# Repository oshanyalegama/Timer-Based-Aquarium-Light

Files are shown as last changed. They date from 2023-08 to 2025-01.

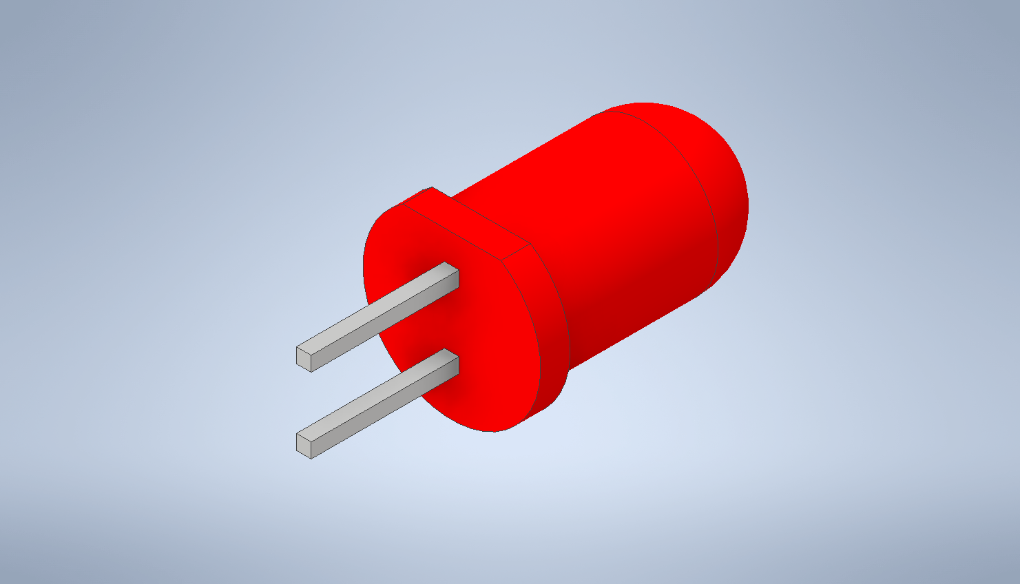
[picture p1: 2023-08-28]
Enclosure/Initial Design/Solidworks/BTG_901_BT_001_LED_5mm_Rot/LED_5mm_Rot.bmp

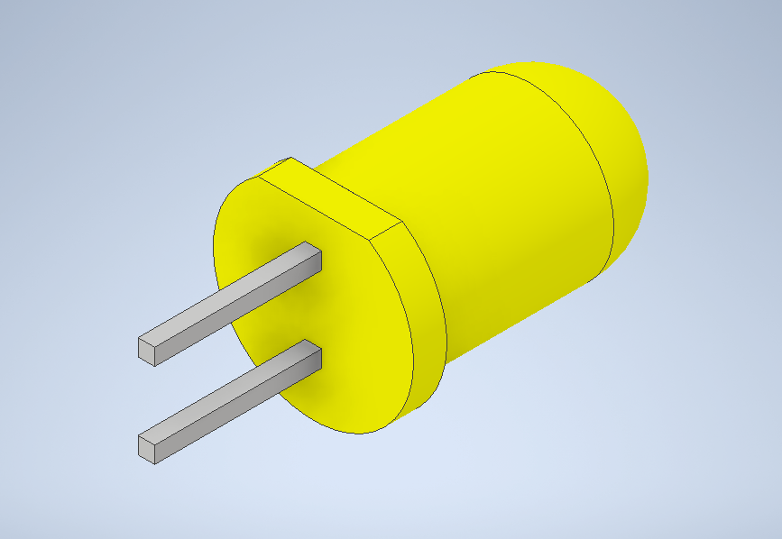
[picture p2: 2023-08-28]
Enclosure/Initial Design/Solidworks/BTG_901_BT_002_LED_5mm_Yellow/LED_5mm_Yellow.bmp

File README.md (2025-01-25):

# Timer-Based Aquarium Light

This project presents a **timer-based aquarium light**, an innovative and user-friendly solution for aquarium maintenance. The device automates light exposure for aquarium fish and plants, ensuring optimal health and growth. Designed for simplicity, the system is powered by the **ATmega328P microcontroller** and integrates an **Arduino Relay Module** for seamless switching based on time.



## Key Features
- **Programmable Timers**: Choose between three preset durations (8, 10, or 12 hours), ideal for different aquatic species and environmental needs.
- **Easy Reset**: A long-press reset button simplifies reconfiguration.
- **User-Friendly Design**: Visual indicators (LEDs) display the active timer setting, making it intuitive to use.
- **Compact and Lightweight**: Enclosure dimensions: 12cm x 7cm x 50cm, weighing less than 100g.
- **Universal Compatibility**: Designed for aquarium lights operating at 12V DC.

## Implementation
The system comprises:
1. **Power Supply Unit**: Converts 240V AC to 12V DC for operation.
2. **Control Unit**: Processes user inputs and manages timer functions using the ATmega328P microcontroller.
3. **Relay Module**: Controls power delivery to the aquarium light.
4. **Indicator LEDs**: Display the selected timer option.
5. **Enclosure**: A robust, 3D-printed housing protects components while ensuring aesthetic appeal.

## Tests and Validation
- Verified power delivery and relay functionality.
- Buttons tested for reliable activation of timer settings.

## Technologies Used
- **ATmega328P Microcontroller**: Core logic unit.
- **Arduino IDE**: Used for programming and debugging.
- **SolidWorks**: For enclosure design.
- **Altium**: For PCB design

---

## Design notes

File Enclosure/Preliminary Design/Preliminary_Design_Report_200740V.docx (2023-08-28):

University of Moratuwa - Wikipedia

Department of Electronic and Telecommunication Engineering

University of Moratuwa

Preliminary Design Report

Yalegama M.M.O.A.B : 200740V

This report is submitted as a partial fulfilment of the module

EN2160 - Electronic Design Realization

15th June 2023

Initial Design

Schematic

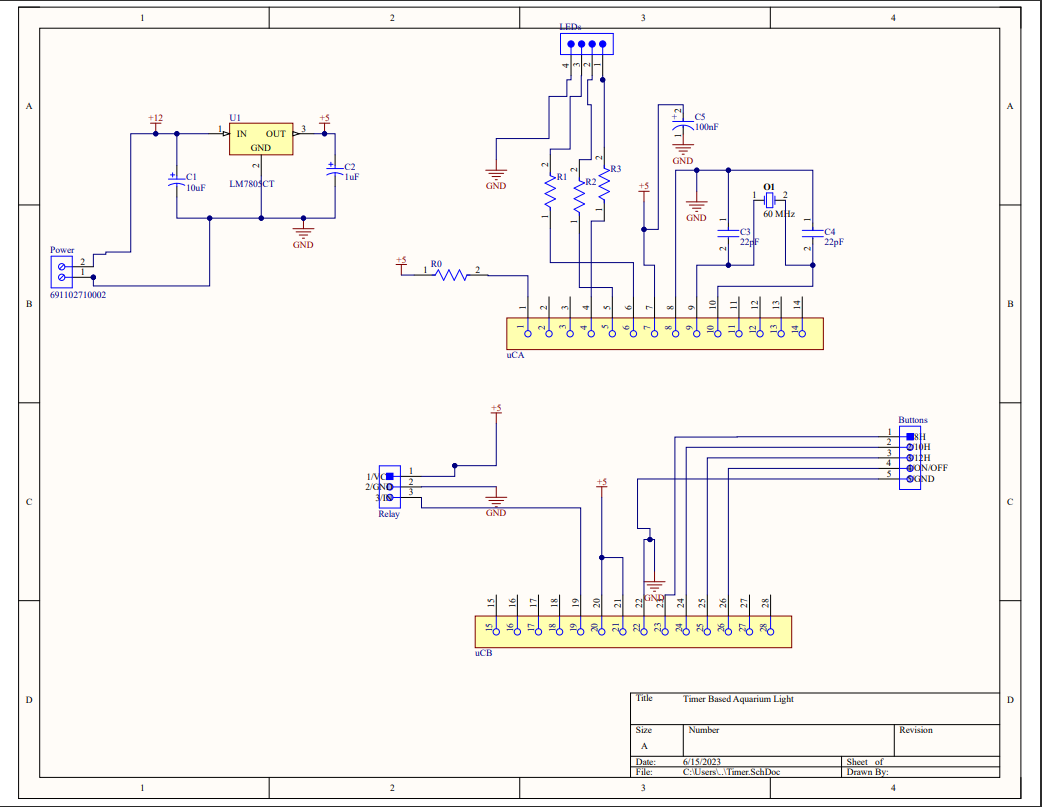
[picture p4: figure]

Enclosure

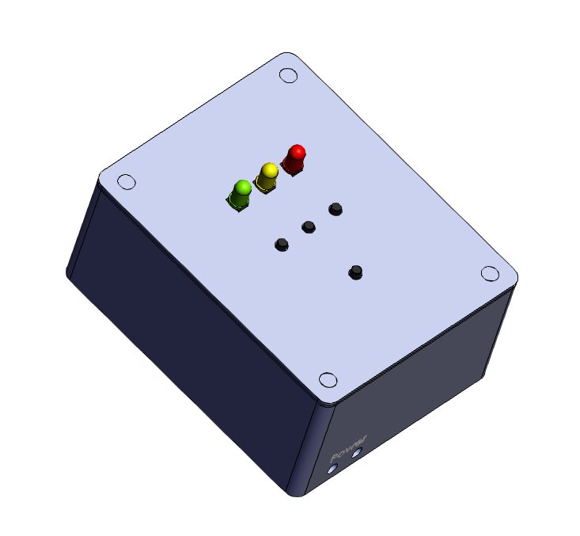
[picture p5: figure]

Problems with the initial design

After studying the course content delivered by Prof. Jayasinghe there were key problems identified about the initial design of the product.

- The enclosure had too many sharp edges that restricted it from being molded, which would be necessary for mass production.
- The design of the device was not informed by user feedback and hence the success of the product was questionable.
- The schematic documentation was not organized according to the industry standards.
- The simplicity of the device’s functionality wasn’t justified by the cost.

Upon discussing with the members of my group and inquiring users on feedback about the initial design, some problems about the initial design were found.

- The design of the enclosure wasn’t impressive in an aesthetic sense.
- The device didn’t provide enough functionality.
- The functionality provided by the device wasn’t sufficient compared to the cost of the product.
- The user interface was not informative enough and the user didn’t receive enough information regarding the operation of the device.

Considering these discoveries, the enclosure and functionality of the new design of the product was made such that these problems were addressed, and the suggested improvements were incorporated.

Enclosure:

The newer enclosure has fillet edges and sides with draft angles that make it possible to be molded for mass production. The enclosure was made to be aesthetically pleasing and unique. The enclosure contains a more advanced UI, with an LCD to display the state of the timer and a button pad to navigate the menu.

Schematic:

The newer schematic is more compliant with the industry standard rules. It added an LCD module for added functionality and to make more efficient use of the capability of the Atmega328P chip. The functionality of the device was also expanded, using the microcontroller to set user defined times instead of fixed times as was before.

Final Design

Schematic

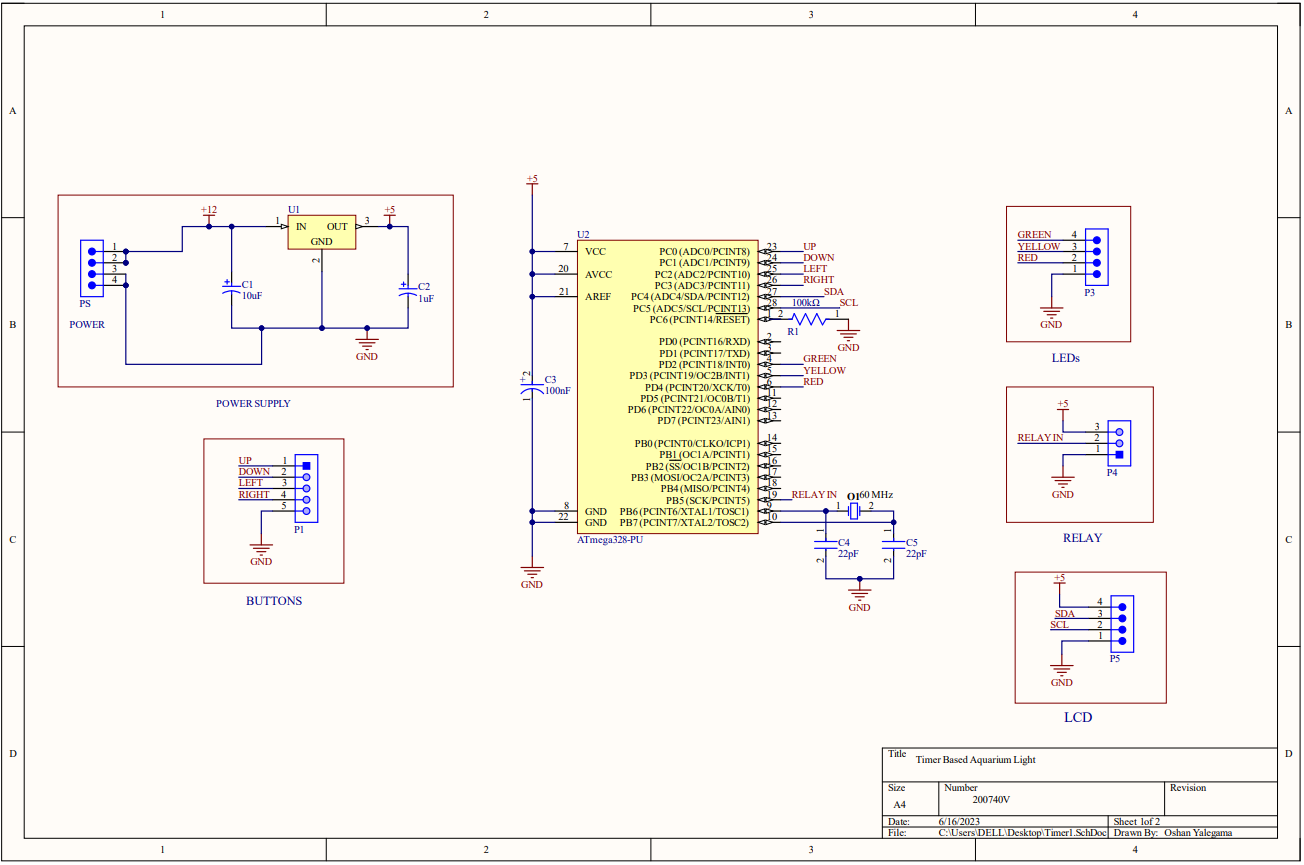
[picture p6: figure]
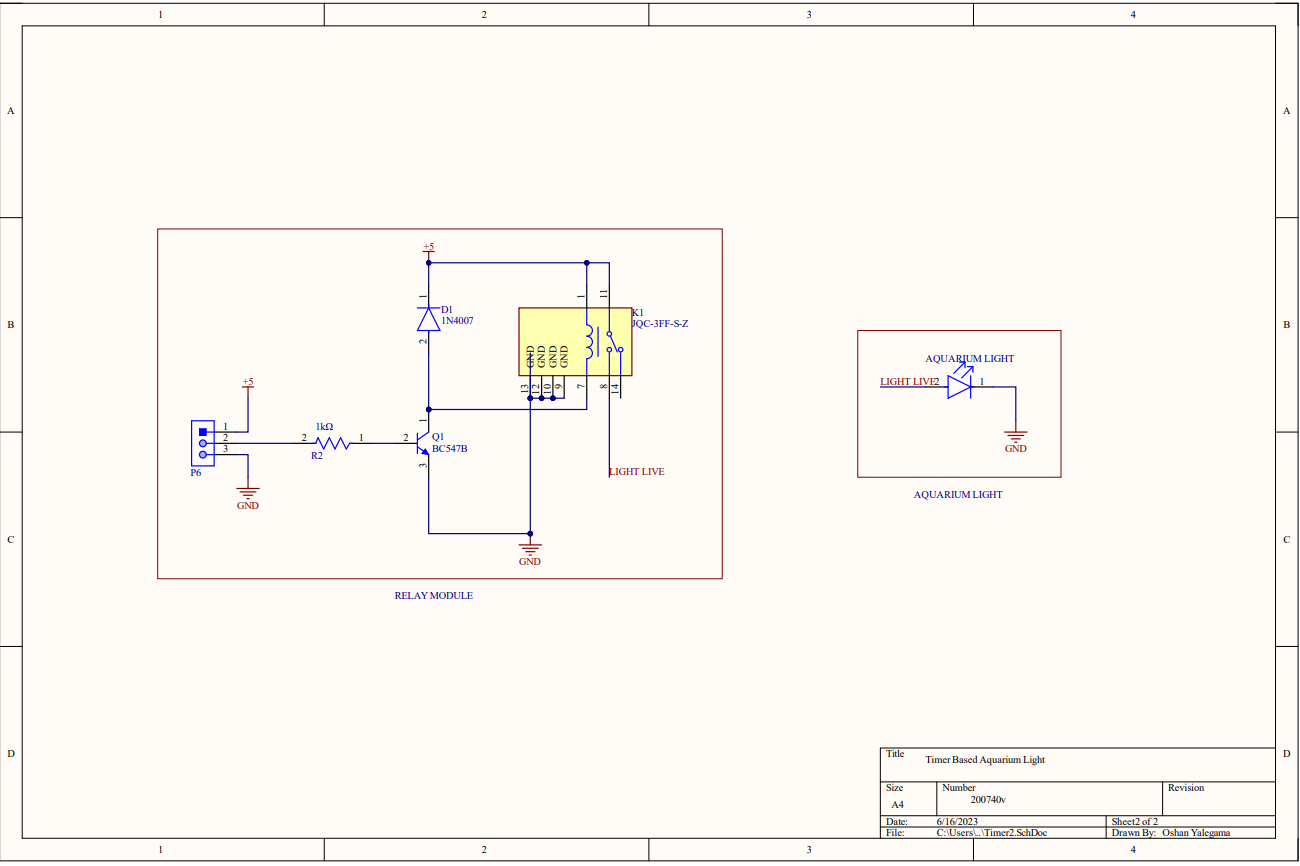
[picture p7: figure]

Enclosure

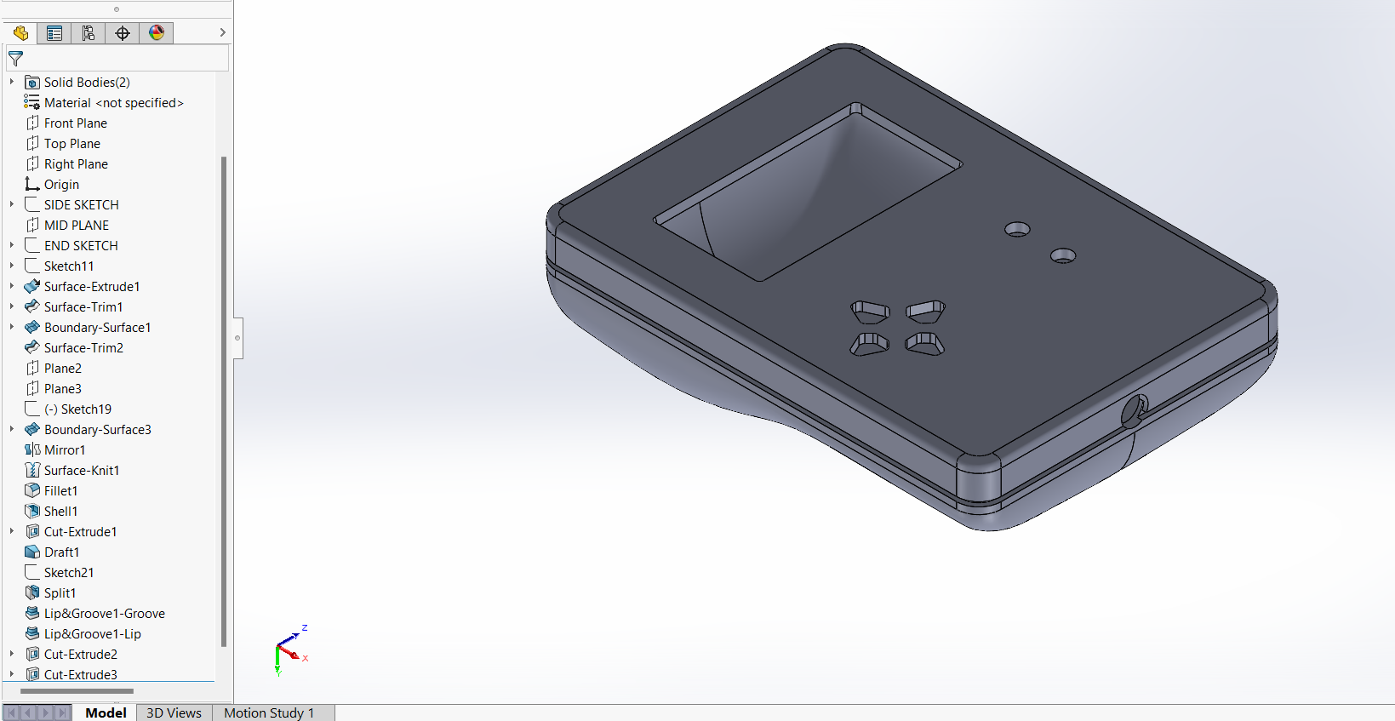
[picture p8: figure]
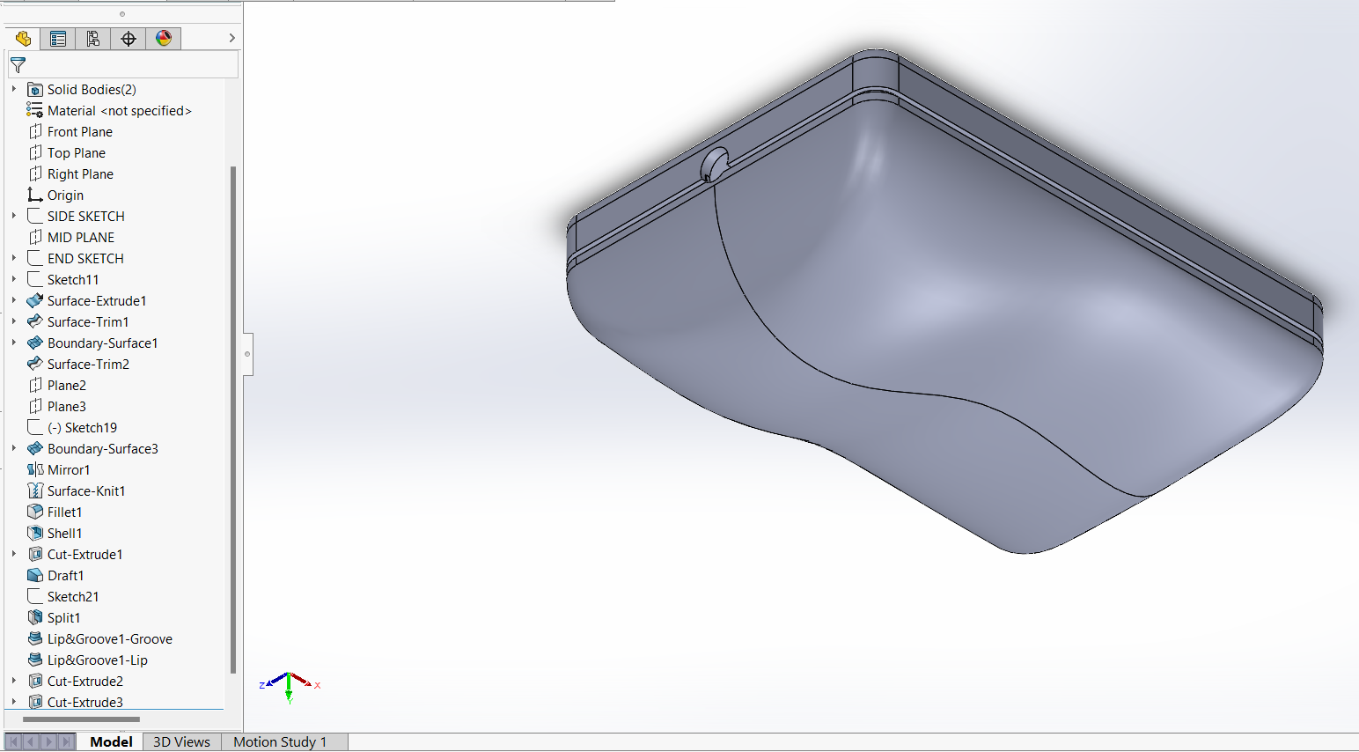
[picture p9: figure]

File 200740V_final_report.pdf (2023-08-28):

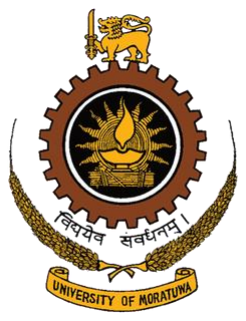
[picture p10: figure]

Department of Electronic and Telecommunication Engineering

University of Moratuwa

Timer Based Aquarium Light

Yalegama M.M.O.A.B : 200740V

This report is submitted as a partial fulfilment of the module

EN2160 - Electronic Design Realization

26th July 2023

## Contents

## Abstract

The aim of this project was to create a timer-based aquarium light which is a device that can be used in fish tanks to light the fish tank for a specified period. The user has 3 options to select from for the period with the added feature of being able to turn it off and on as normal use. The project utilized the ATmega328p microcontroller and the Arduino Relay module to deliver a switching action based on time. The final design of the product operated at a voltage of 12V and was suitable for use with aquarium lights with rated operating voltage of 12V.

## 1. Introduction

### 1.1 Problem Description and Overview

Contrary to popular belief, fish keeping can be a very delicate task in terms of maintenance. Ensure the fish and plants in the aquarium tank get the proper amount of nutrition and exposure to light is critical. The amount of light especially can be a rather tedious to control since it’s a daily activity that requires careful timing. The time of exposure to light also depends on several factors such as the species of fish and the amount of ambient light. However, it typically ranges between 8 and 12 hours per day.

This problem is addressed by creating an aquarium light based on a timer that will turn off after one of three specified times, namely, 8, 10, and 12. This is indicated by 3 led lights on the enclosure.

### 1.2 Functionality and key features

The product consists of an aquarium light that turns off after a set interval of time. The timer options are selected according to the requirements of fish and plant life to thrive. The device can be used in medium sized tanks and light should be attached to the rood of the fish tank. The recommended timer option for a medium sized fish tank is 8 hours and should be turned on between sun rise and sun set.

Reset feature – By holding the on/off button for a 5 second duration it resets any timer feature that had been turned on at that time.

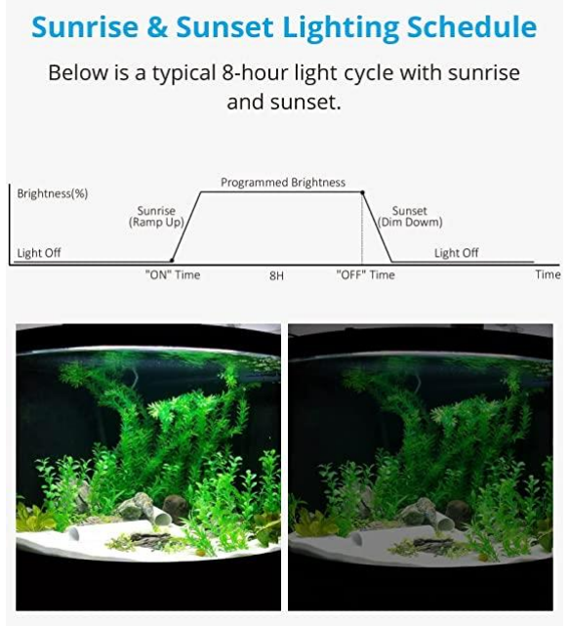
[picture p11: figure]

### 1.3 Specifications

Size – 12 cm length x 7 cm width x 50 cm height

Weight – less than 100g

Enclosure Colour – Black

LED Colours – Green, Yellow and Red and red to indicate 8 hours, 10 hours and 12 hours respectively.

Operation Mode - On or Off

Operating Voltage - Power supply should be connected to 240V / 60Hz supply. LED lights operate at 12V DC.

Timing Options - Three sets of timers. 8H, 10H and 12H.

Additional features –

Easy to set up device.

Simple and easy to use User Interface

## 2. Implementation

### 2.1 Functional Block diagram

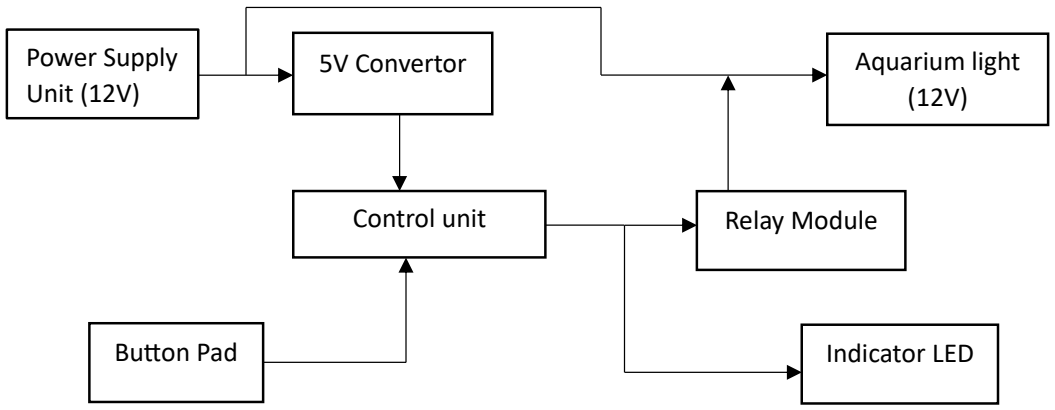
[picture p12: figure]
Button Pad; Relay Module; Indicator LED; Aquarium light (12V); Power Supply Unit (12V); 5V Convertor; Control unit

### 2.2 Mechanism

The power supply unit will supply a 12 V DC voltage that will be interrupted by a relay that will activated by a control signal that will come from the control unit. The control unit will be given instructions from the user using the button pad. The control unit will also send signals to the indicator LED to show the user which option of timer is being activated at the specific time.

### 2.3 Component Selection

Power Supply Unit : 12 V 2A Power Adaptor

5V Convertor : Capacitors (470 uF, 1 uF), LM7805, Diode IN4007

Control Unit : 22 AWG wire, 220 ohm resistors, 10 uF capacitors, ATMega328P, 16 MHz crustal oscillator

Button Pad : 4 push buttons

2.4 Schematic Diagram

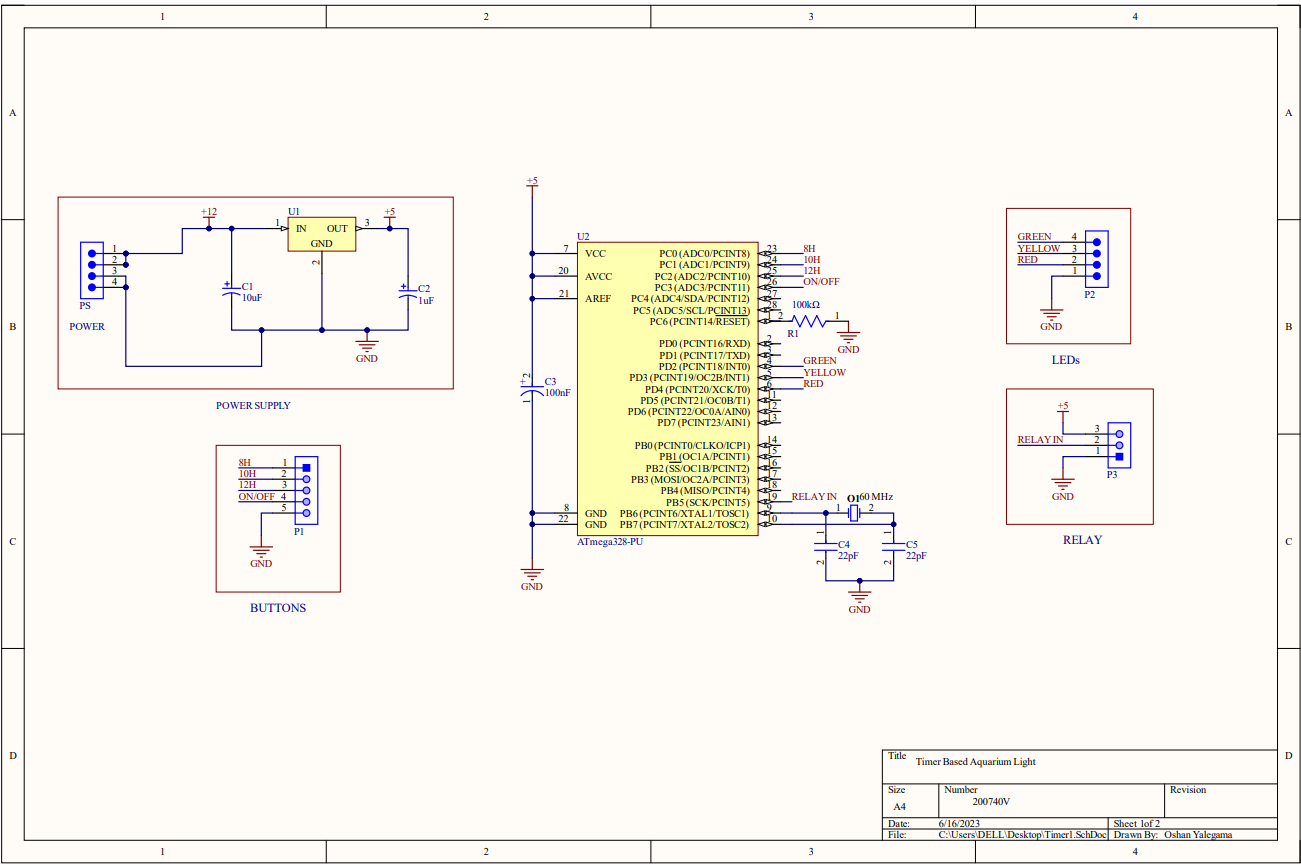
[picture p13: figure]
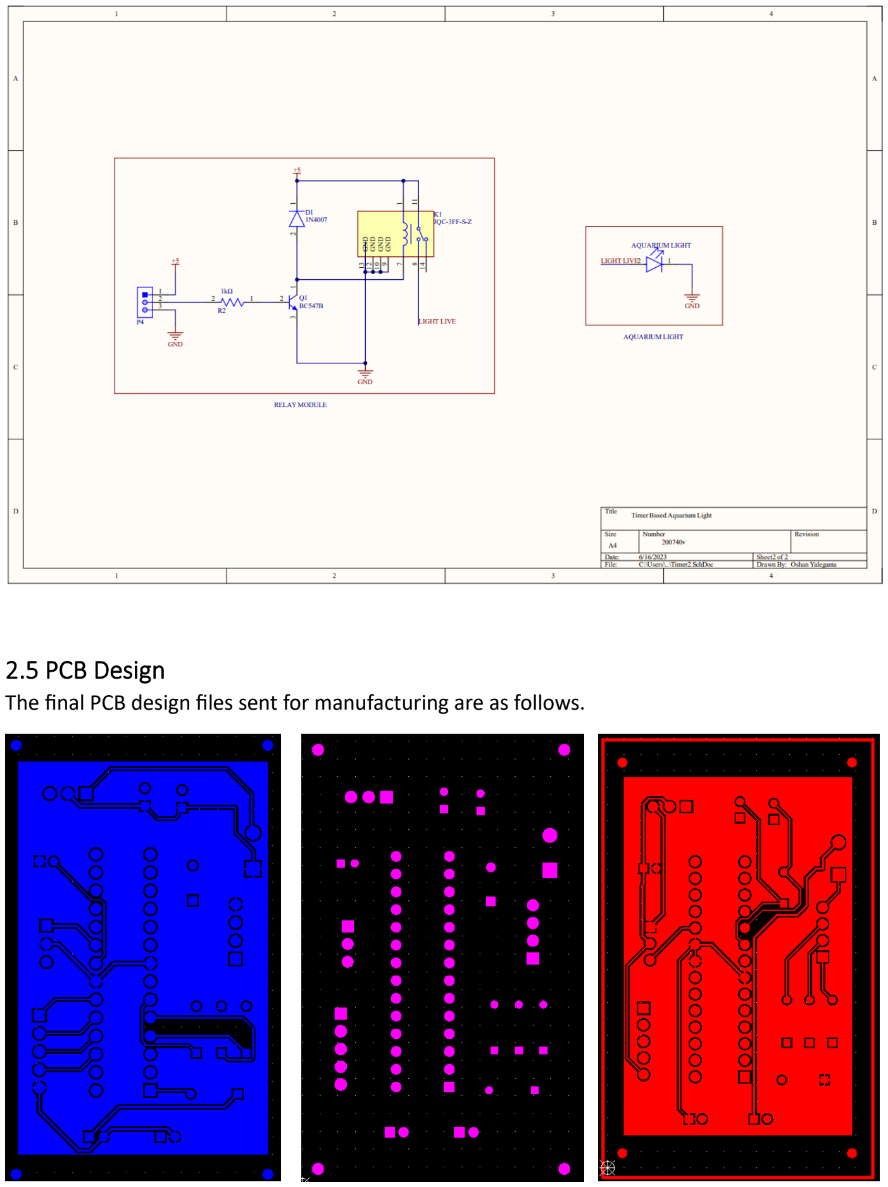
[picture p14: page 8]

### 2.5 PCB Design

The final PCB design files sent for manufacturing are as follows.

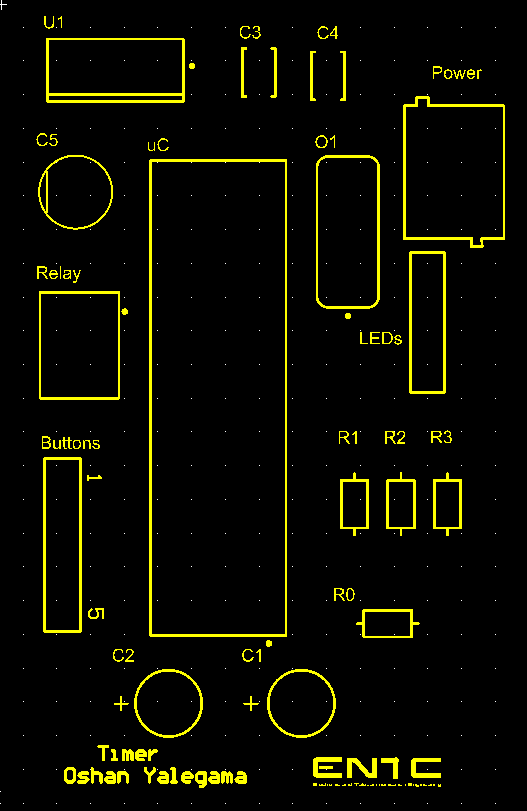
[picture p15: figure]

### 2.6 Final PCB

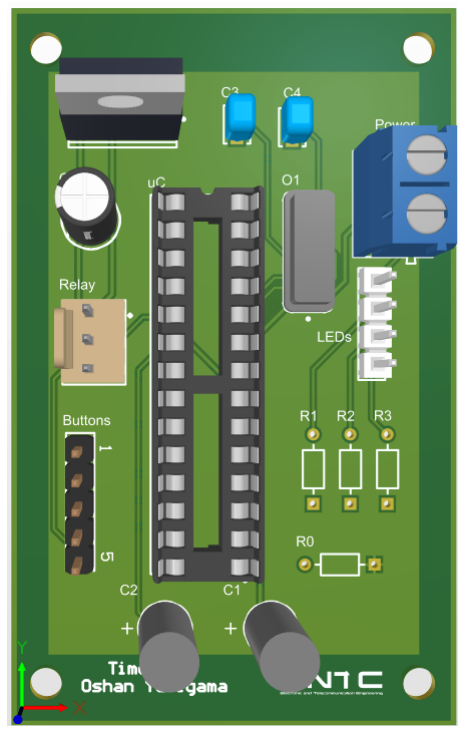
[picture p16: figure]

## 3. Enclosure

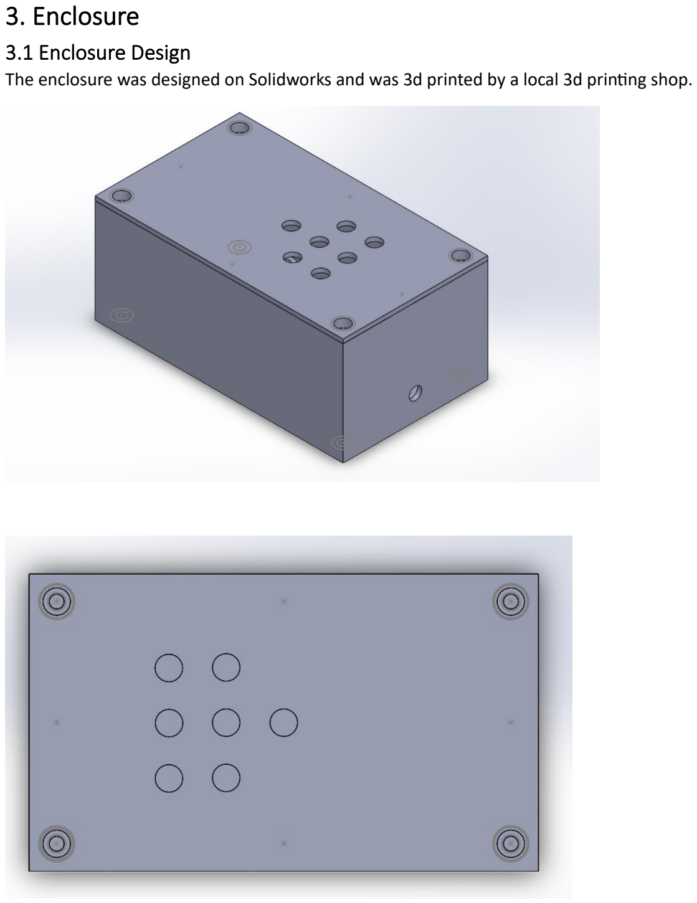
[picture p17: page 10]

### 3.1 Enclosure Design

The enclosure was designed on Solidworks and was 3d printed by a local 3d printing shop.

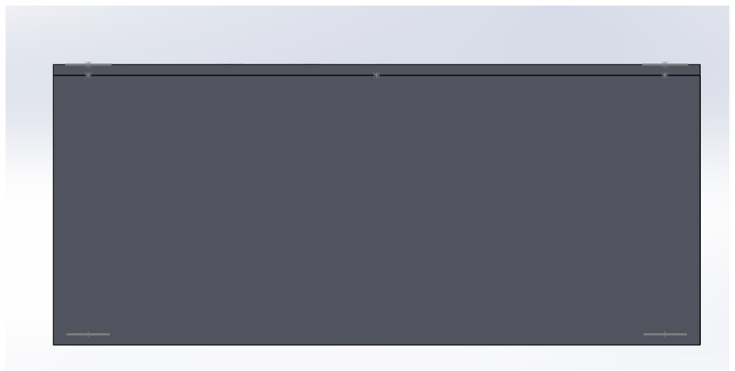
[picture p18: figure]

3.2 The 3D Printed Enclosure

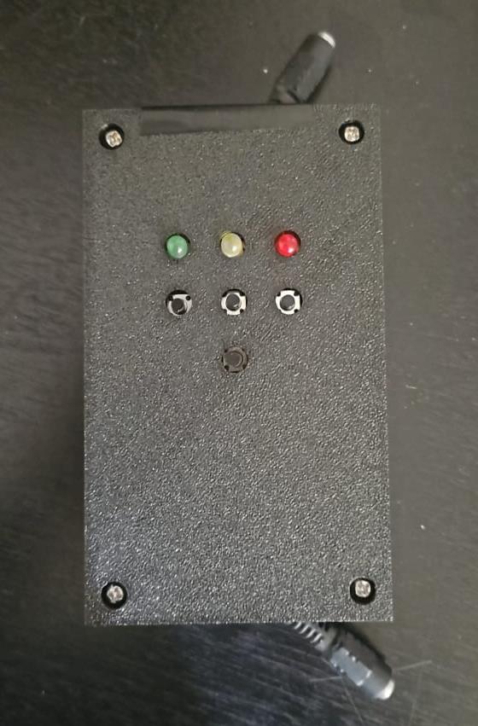
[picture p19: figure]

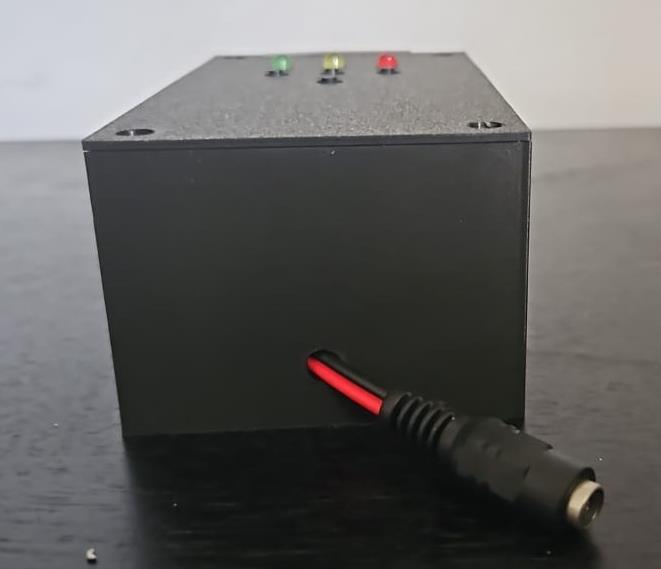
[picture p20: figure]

## 4. Assembly Instructions

### 4.1 Components required

12 V 2A Power Adaptor

Capacitors (470 uF, 1 uF)

LM7805 voltage regulator

Diode IN4007

22 AWG wire

220 ohm resistors

10 uF capacitors

ATMega328P

16 MHz crustal oscillator

4 push buttons

4 indicator LEDs

### 4.2 Parts Assembly

All components are through hole and hence should be soldered as appropriate.

The PCB and Relay Module should be mounted to the platforms on the enclosure using 3mm screws and 2mm screws respectively. The button pad should be mounted to the enclosure lid using the supports printed. This is demonstrated by the following image.

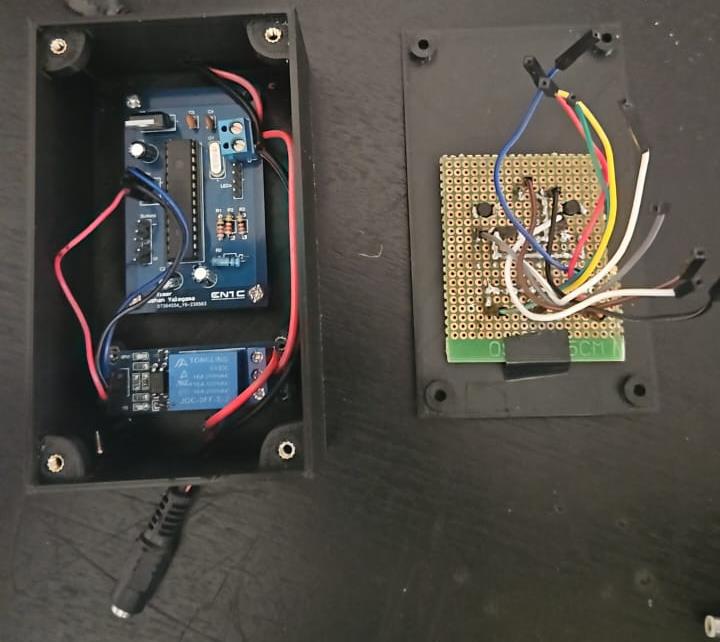
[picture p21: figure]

The PCB and Relay orientations are as in the image.

The enclosure should be closed with the lid and tightened using 3mm screws.

## 5. Bill of Materials

The following list has been compiled with an assumed USD conversion rate of Rs. 332.

Component | Supplier | Unit Price | Quantity | Total Price(LKR)
Atmega 328P | LCSC Electronics | 4.98 USD | 2 | 1653.36
IC Socket | LCSC Electronics | 0.0464 USD | 5 | 77.024
Crystal oscillator | LCSC Electronics | 0.1126 USD | 2 | 74.7664
10uF capacitor | LCSC Electronics | 0.043 USD | 10 | 142.76
22pF capacitor | LCSC Electronics | 0.01 USD | 20 | 33.2
10k ohm resistor | LCSC Electronics | 0.086 USD | 10 | 285.22
220 ohm resistor | LCSC Electronics | 0.086 USD | 20 | 570.44
LM7805 | LCSC Electronics | 0.178 USD | 2 | 118.192
LED | LCSC Electronics | 0.138 USD | 10 | 458.16
Arudino Relay Module | Tronic.lk | 180 LKR | 2 | 360
12V Power Adapter | Tronic.lk | 1100 LKR | 1 | 1100
PCB | JLCPCB | 7.42 USD | 1 | 2463.44
Enclosure | Xyder Labs | 4800 LKR | 1 | 4800
Total | Rs. 12,136. 5924

## 6. Tests for Functionality

Power delivery test.

A dc voltage of 12 V should be delivered to the output connector when the device is in timer mode and should have 0 V otherwise. A dc voltage of 12 V should be supplied to the input of the PCB, and this can be checked by probing the input terminal block. If not, there might be a lose connection inside the enclosure.

Relay module operation

The operation of the Relay module can be tested by checking whether the green indicator light is on when the device is not in timer mode.

Button pad operation

The buttons can be tested by simply testing whether each button activates the necessary timing of the device. For this, it must be ensured that the microcontroller is properly operating. The on off button should also provide properly resetting the device’s timing configuration.

## 7. References

How Long Should You Leave a Aquarium Lights On? - AquariumNexus (https://www.aquariumnexus.com/how-long-aquarium-lights-on/)

(20) Arduino Timer Control Relay Devices - YouTube (https://www.youtube.com/watch?v=JjigJALjN5Y)
Building an Arduino on a Breadboard | Arduino Documentation | Arduino Documentation (https://docs.arduino.cc/hacking/hardware/building-an-arduino-on-a-breadboard)

220V TO 12V DC CONVERTER CIRCUIT DIAGRAM - Electronic Projects, Power Supply Circuits, Circuit Diagram symbols, Audio Amplifier Circuit pdf & Engineering Projects (circuitsarena.com) (https://www.circuitsarena.com/2019/04/220v-to-12v-dc-converter-circuit-diagram.html)

LM7805 * LM7806 * LM7808 * LM7809 * LM7810 * LM7812 * LM7815 * LM7818 * LM7824 * LM7805A * LM7806A * LM7808A *LM7809A * LM7810A * LM7812A * LM7815A * LM7818A * LM7824A 3-Terminal 1A Positive Voltage Regulator (Preliminary) (components101.com) (https://components101.com/sites/default/files/component_datasheet/LM7812-Datasheet.pdf)

## Appendix

The following code was used to program the microcontroller using the Arduino platform and using the Arduino IDE.

//OUTPUT PINS

int relayPin = 13; // The pin we're using

int ledPin1 = 2; // red(button 1)

int ledPin2 = 3; // yellow(button 2)

int ledPin3 = 4; // green(button 3)

//DURATIONS

long duration1 = 10000; // The duration for button 1 (1 minute)

long duration2 = 20000; // The duration for button 2 (5 minutes)

long duration3 = 30000; // The duration for button 3 (30 minutes)

//BUTTONS

int buttonPin1 = A0; // The pin for button 1

int buttonPin2 = A1; // The pin for button 2

int buttonPin3 = A2; // The pin for button 3

int buttonPin4 = A3; //the toggle pin

//BUTTON STATES

bool buttonState1 = false; // The state of button 1 (pressed or not pressed)//A0,23, 8H

bool buttonState2 = false; // The state of button 2 (pressed or not pressed)//A1,24

bool buttonState3 = false; // The state of button 3 (pressed or not pressed)//A2.25

bool buttonState4 = false; // variable for storing the toggle button state

//BUTTON CHARACTERISTICS

unsigned long startTime; // The time the pin was turned on

unsigned long pressTime;

int resetTime = 5000;

// OTHER VARIABLES

bool reset = false;

int ledState = LOW; //variable for storing the led state

//SETUP

void setup() {

pinMode(ledPin1, OUTPUT);

pinMode(ledPin2, OUTPUT);

pinMode(ledPin3, OUTPUT);

pinMode(relayPin, OUTPUT);

pinMode(buttonPin1, INPUT_PULLUP); // Set the button 1 pin as an input with pullup resistor

pinMode(buttonPin2, INPUT_PULLUP); // Set the button 2 pin as an input with pullup resistor

pinMode(buttonPin3, INPUT_PULLUP); // Set the button 3 pin as an input with pullup resistor

pinMode(buttonPin4, INPUT_PULLUP); // Set the button 4 pin as an input with pullup resistor

Serial.begin(9600); // Initialize serial communication

}

//CODE

void loop() {

//READING THE STATE OF THE BUTTONS

buttonState1 = digitalRead(buttonPin1); // Read the state of button 1

buttonState2 = digitalRead(buttonPin2); // Read the state of button 2

buttonState3 = digitalRead(buttonPin3); // Read the state of button 3

buttonState4 = digitalRead(buttonPin4); // Read the state of button 3

//TOGGLING

if (buttonState4== LOW) {

Serial.println("yeah");

ledState = !ledState;

digitalWrite(relayPin, ledState);

delay(500); // Debounce delay to prevent rapid toggling

}

//PRESSING BUTTON 1

if (buttonState1 == LOW) { // If button 1 is pressed

Serial.println("yeah");

digitalWrite(ledPin1, HIGH); //turn led1 on

digitalWrite(relayPin, HIGH);//turn relay on

startTime = millis(); // Store the time the pin was turned on

while (millis() - startTime <= duration1) { // While relay is on for less than duration1 time

//RESET Code

buttonState4 = digitalRead(buttonPin4);//check the toggle button

if (buttonState4== LOW){//if the toggle button is pressed

pressTime = millis();

reset = true;

while (millis() - pressTime <= resetTime){//if it's released before the reset time

buttonState4= digitalRead(buttonPin4);

if (buttonState4== HIGH){

reset = false;//don't reset

}

}

if (reset){

Serial.println("Stopped");

break;

}

}

}

digitalWrite(ledPin1, LOW); //Turn led off

digitalWrite(relayPin, LOW); // Turn the relay off

delay(1000); // Wait for a second before starting again

}

if (buttonState2 == LOW) { // If button 1 is pressed

digitalWrite(ledPin2, HIGH);

digitalWrite(relayPin, HIGH); // Turn the pin on

startTime = millis(); // Store the time the pin was turned on

while (millis() - startTime <= duration2) { // While the pin should be on

//COLOUR CHANGING CODE

if (millis() - startTime >= (duration2- duration1)) {

digitalWrite(ledPin2, LOW);

digitalWrite(ledPin1, HIGH);

//RESET Code

buttonState4= digitalRead(buttonPin4);

if (buttonState4== LOW){

pressTime = millis();

reset = true;

while (millis() - pressTime <= resetTime){

buttonState4= digitalRead(buttonPin4);

if (buttonState4== HIGH){

reset = false;

}

}

if (reset){

Serial.println("Stopped");

break;

}

}

delay(1000); // Wait for one second

}

}

digitalWrite(ledPin2, LOW);

digitalWrite(ledPin1, LOW);

digitalWrite(relayPin, LOW); // Turn the relay off

delay(1000); // Wait for a second before starting again

}

if (buttonState3 == LOW) { // If button 1 is pressed

digitalWrite(ledPin3, HIGH);

digitalWrite(relayPin, HIGH); // Turn the pin on

startTime = millis(); // Store the time the pin was turned on

while (millis() - startTime <= duration3) { // While the pin should be on

//COLOUR CHANGING CODE

if (millis() - startTime >= (duration3-duration2)) {

if (millis() - startTime >= (duration3 - duration1)) {

digitalWrite(ledPin2, LOW);

digitalWrite(ledPin1, HIGH);

}

else{

digitalWrite(ledPin3, LOW);

digitalWrite(ledPin2, HIGH);

}

}

//RESET Code

buttonState4= digitalRead(buttonPin4);

if (buttonState4== LOW){

pressTime = millis();

reset = true;

while (millis() - pressTime <= resetTime){

buttonState4= digitalRead(buttonPin4);

if (buttonState4== HIGH){

reset = false;

}

}

if (reset){

Serial.println("Stopped");

break;

}

}

delay(1000); // Wait for one second

}

digitalWrite(ledPin3, LOW);

digitalWrite(ledPin2, LOW);

digitalWrite(ledPin1, LOW);

digitalWrite(relayPin, LOW);

delay(1000); // Wait for a second before starting again

}

}

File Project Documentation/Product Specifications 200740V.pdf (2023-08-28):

# Timer Based Aquarium Light

### Index number: 200740V

Product description

The product consists of an aquarium light that turns off after a set interval of time. The timer options are selected according to the requirements of fish and plant life to thrive. The device can be used in medium sized tanks and light should be attached to the rood of the fish tank. The recommended timer option for a medium sized fish tank is 8 hours and should be turned on between sun rise and sun set.

Product Specifications

Size

- LED light – 25 cm length and 10 cm diameter
- Timing device – 8 cm length x 5 cm width

Weight

- Entire unit will be less than 100 g.

Enclosure Colour

- Black

LED Colour

- White

Operation Mode

- On or Off

Operating Voltage

- Power supply should be connected to 240V / 60Hz supply.
- LED lights operate at 12V DC.

Timing Options

- Three sets of timers. 8H, 10H and 12H. There is also an option to turn the timer off.

Additional features

- The lights will be waterproofed to be suitable for use in a fish tank.
- Easy to set up device.
- Simple and easy to use User Interface.

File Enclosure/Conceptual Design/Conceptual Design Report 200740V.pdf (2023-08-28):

# Index No : 200740V

# Name : Yalegama MMOAB

The following document shows the design process that was taken to determine the final product schematic and enclosure for the product.

An acknowledgment should be made to the team members that contributed their ideas to improve the design.

Selani Indrapala (200232P)

Leon Fernando (200164H)

Malith Jayalath (200247P)

Avishka Herath (200212F)

Nushrath Amana (200022X)

Dusara Gamidu (200179H)

## Design 1

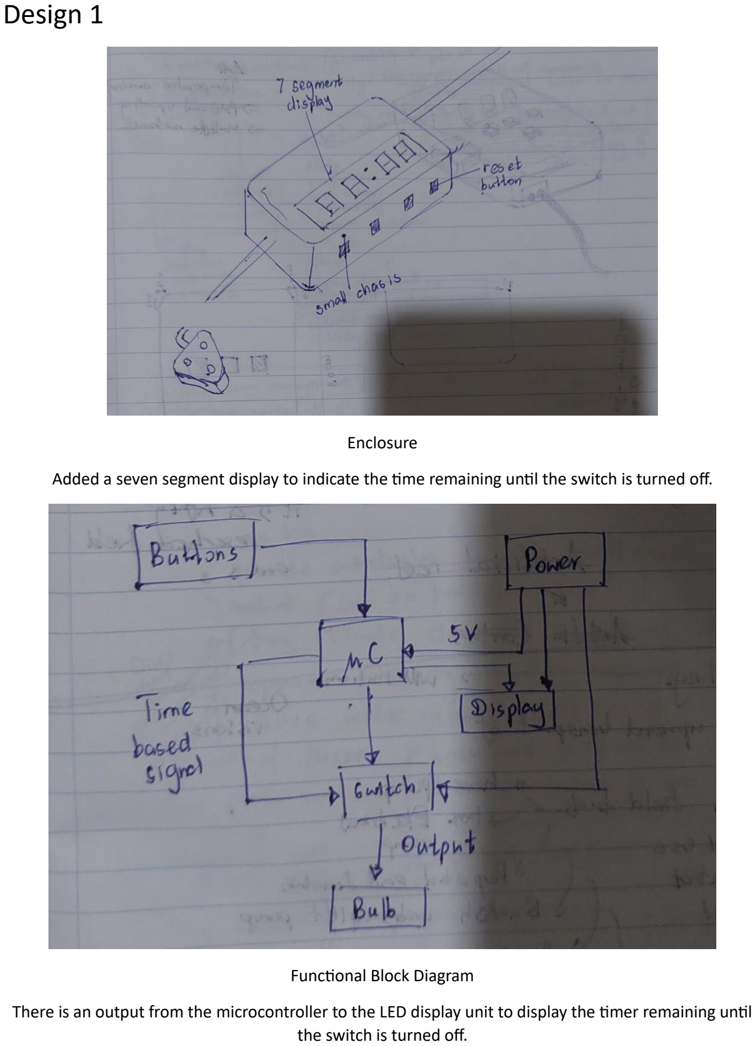
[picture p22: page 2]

Enclosure

Added a seven segment display to indicate the time remaining until the switch is turned off.

Functional Block Diagram

There is an output from the microcontroller to the LED display unit to display the timer remaining until the switch is turned off.

## Design 2

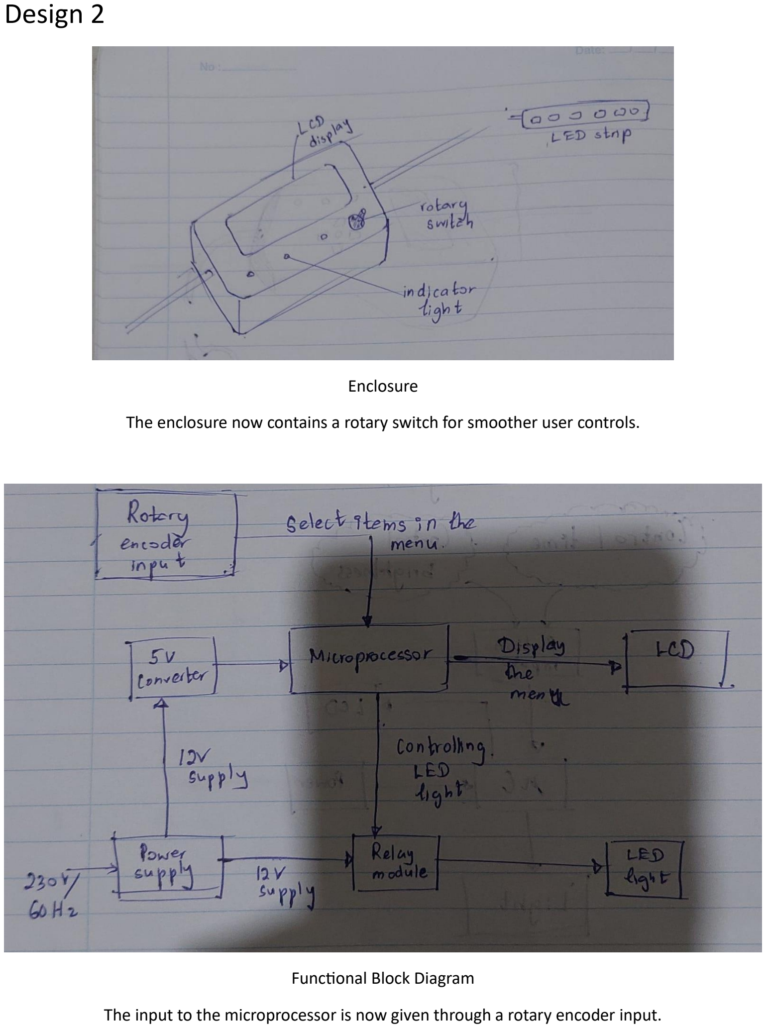
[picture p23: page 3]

Enclosure

The enclosure now contains a rotary switch for smoother user controls.

Functional Block Diagram

The input to the microprocessor is now given through a rotary encoder input.

## Design 3

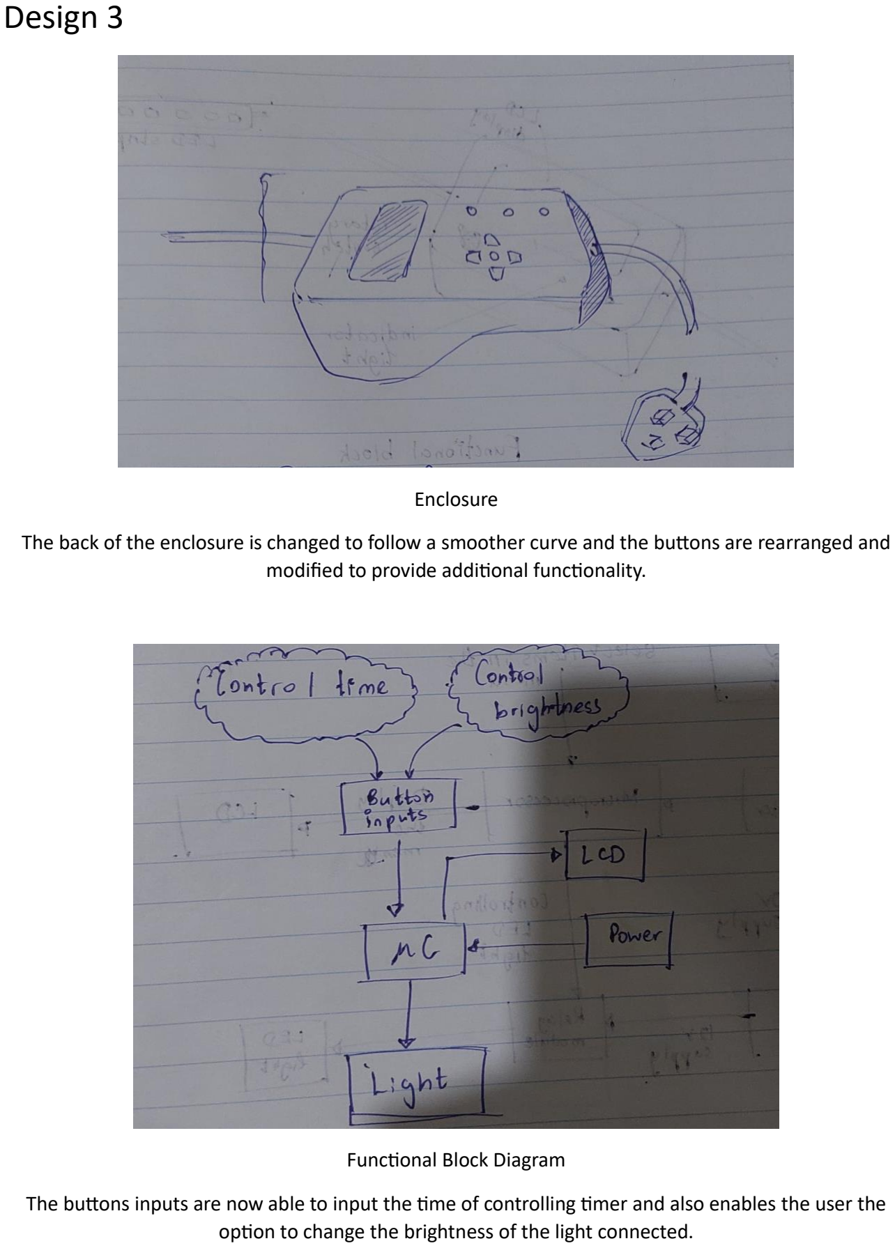
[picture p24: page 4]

Enclosure

The back of the enclosure is changed to follow a smoother curve and the buttons are rearranged and modified to provide additional functionality.

Functional Block Diagram

The buttons inputs are now able to input the time of controlling timer and also enables the user the option to change the brightness of the light connected.

## User Centered Design (Design 4)

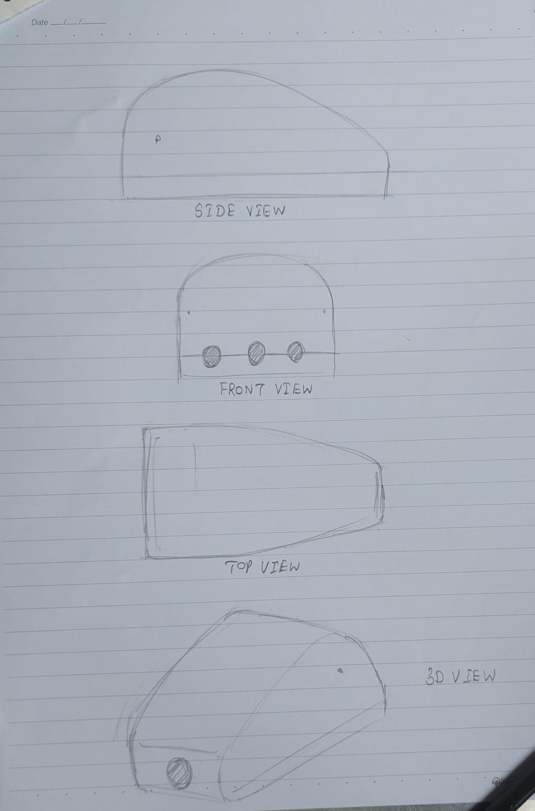
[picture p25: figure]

Enclosure

The enclosure now contains additional ports to allow connectivity of multiple decices.

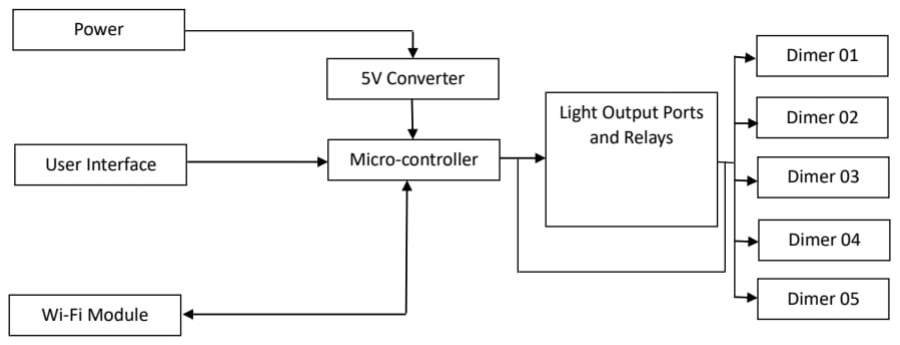
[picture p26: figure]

Functional Block Diagram

Adds dimmers and multiple relays to control the brightness and timer settings of multiple lights that are connected. A Wi-Fi module is added for remote control of the device.

### Selection Matrix

### Enclosure

| Design 1 | Design 2 | Design 3 | Design 4
Protection | 3 | 3 | 5 | 3
Size and Space Optimization | 5 | 5 | 3 | 5
Access and Ergonomics | 3 | 3 | 5 | 5
Aesthetics | 3 | 3 | 5 | 5
Thermal Management | 3 | 3 | 3 | 3
Material Selection | 5 | 5 | 5 | 5
Compliance and Standards | 5 | 5 | 5 | 3
Total | 27 | 27 | 31 | 29

### Schematic

| Design 1 | Design 2 | Design 3 | Design 4
User-Centered | 5 | 3 | 5 | 5
Functionality | 5 | 5 | 3 | 5
Performance | 3 | 3 | 5 | 3
Intuitive | 3 | 3 | 5 | 3
Scalability | 3 | 3 | 3 | 5
Reliability | 5 | 3 | 5 | 3
Cost-Effectiveness | 5 | 5 | 5 | 3
Total | 29 | 25 | 31 | 30

From the selection matrices we can determine that design 3 has both the best enclosure and best schematic. Hence, the selected design will be design 3.

## Selected Design (Design 3)


Enclosure

Functional Block Diagram

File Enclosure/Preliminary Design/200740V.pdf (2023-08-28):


DESIGN SKETCHES OF 200740V ENCLOSURE (M.M.O.A.B. Yalegama)

1. FRONT VIEW
2. SIDE VIEW


3. SLANTED VIEW


4. TOP VIEW

SOLIDWORKS DESIGNS


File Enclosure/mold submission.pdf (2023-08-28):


Department of Electronic and Telecommunication Engineering

University of Moratuwa

Solidworks Resubmission

Yalegama M.M.O.A.B : 200740V

This report is submitted as a partial fulfilment of the module

EN2160– Electronic Design Realization

08

th June 2023

## Sketches


Final Enclosure


Side view


Front view

Top view

## Solidworks Enclosure


Full Enclosure

Top component


Bottom Component

## Mold Design


Core and Cavity of the bottom part of the enclosure

Mold Core of the bottom part of the enclosure


Mold Cavity of the bottom part of the enclosure

## Tree Diagrams


Tree Diagram of final enclosure


Tree Diagram of mold design

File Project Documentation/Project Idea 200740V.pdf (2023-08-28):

Product Idea – 200740V

The Product idea is an aquarium light with a timer. Aquarium lights are recommended to be used only for fixed periods of time, so that the fish and plants can be maintained properly.

Similar products can be found below:

NICREW Aquarium Light Timer&Dimmer, Easy to Program Fish Tank Light Controller (amazon.com) (https://www.amazon.com/NICREW-Aquarium-Dimmer-Program-Controller/dp/B08LKQHG5V)

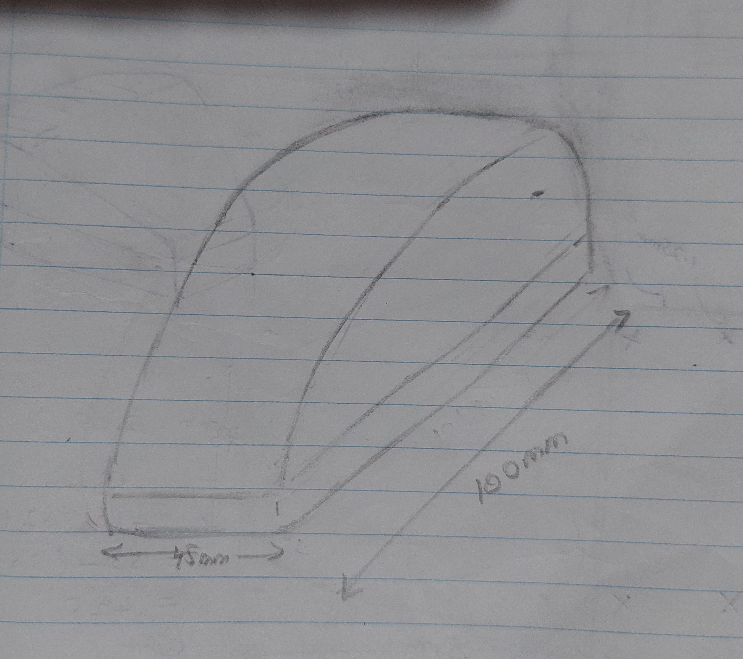
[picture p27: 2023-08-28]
Enclosure/Preliminary Design/Slanted view.jpg

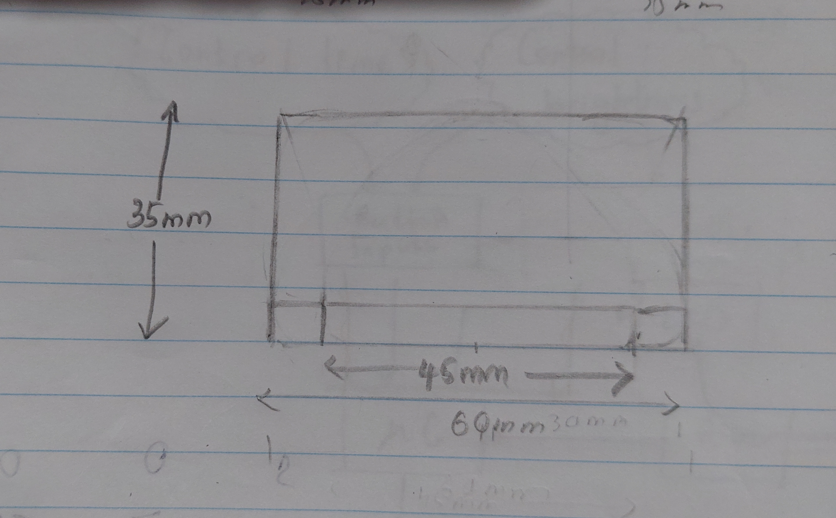
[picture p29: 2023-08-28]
Enclosure/Preliminary Design/Front view.jpg

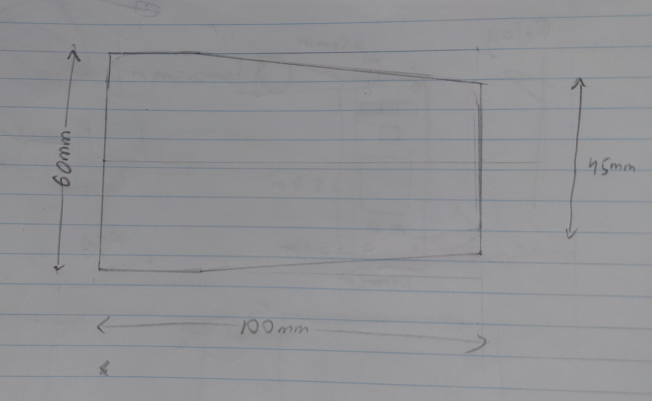
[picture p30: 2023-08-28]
Enclosure/Preliminary Design/Top View.jpg

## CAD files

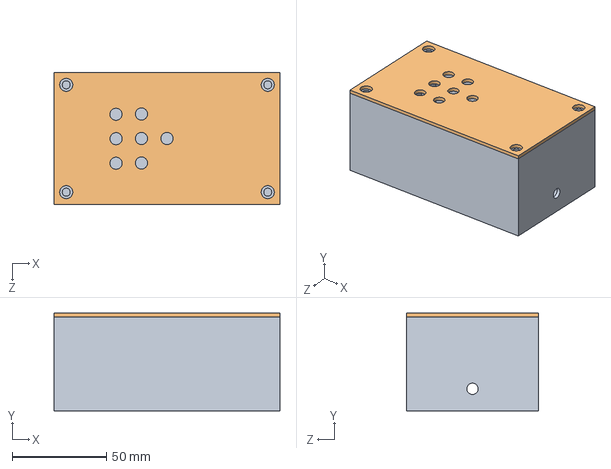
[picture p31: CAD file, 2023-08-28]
Enclosure/Final Printed Designs/past solidworks versioon/Assem1.SLDASM
120.0 x 52.0 x 70.0 mm
Printing
printing bottom

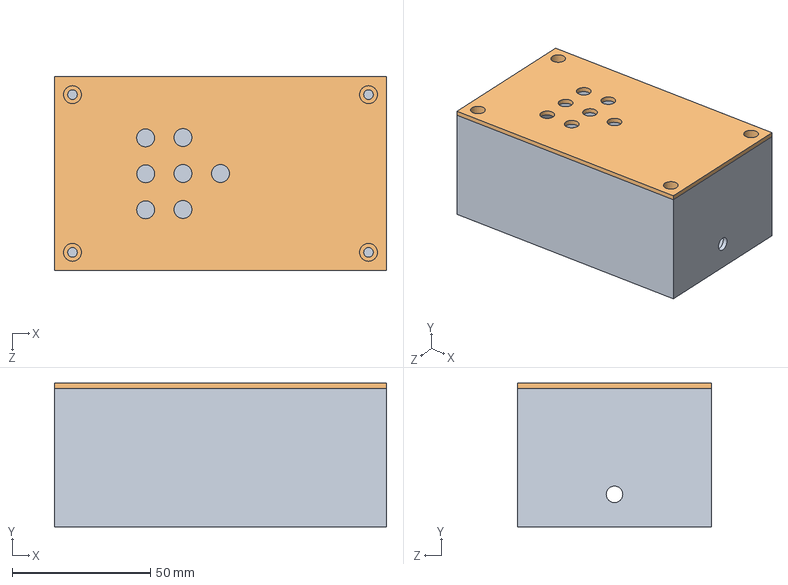
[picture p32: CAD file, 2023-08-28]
Enclosure/Final Printed Designs/second edition/assembly.SLDASM
120.0 x 52.0 x 70.0 mm
final print bottom
final print top

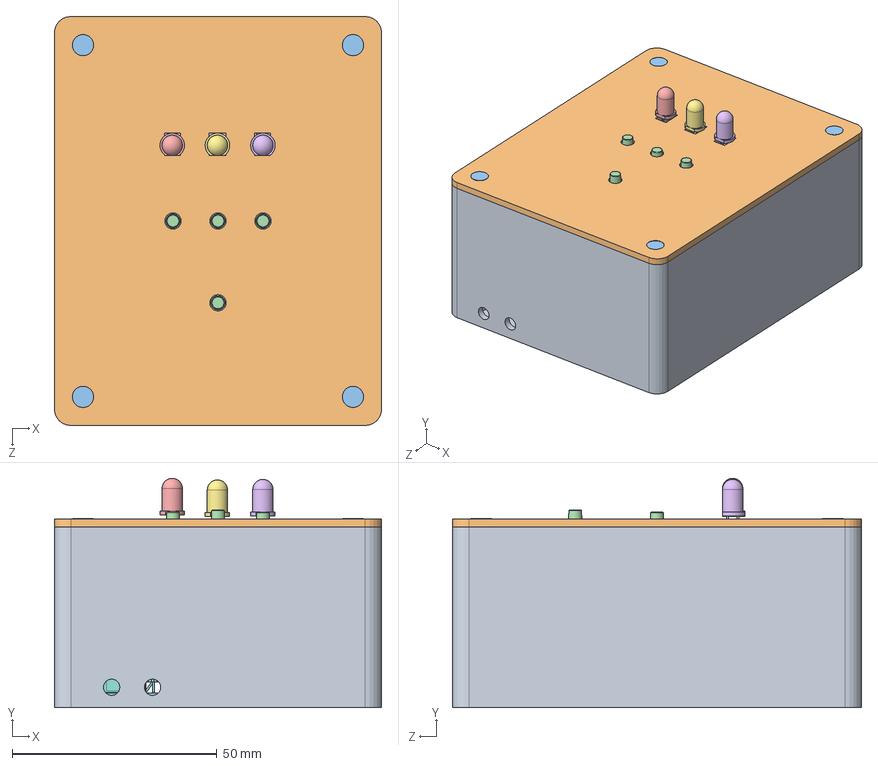
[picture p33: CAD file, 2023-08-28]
Enclosure/Initial Design/Solidworks/Timer final without lid.SLDASM
80.0 x 56.1 x 100.0 mm
Lid
nail x 4
Tactal Switch -Thru 6x 6x8.stp x 4
LED_5mm_Green.stp
LED_5mm_Rot.stp
LED_5mm_Yellow.stp
Relay.stp
Timer PCB eclosur

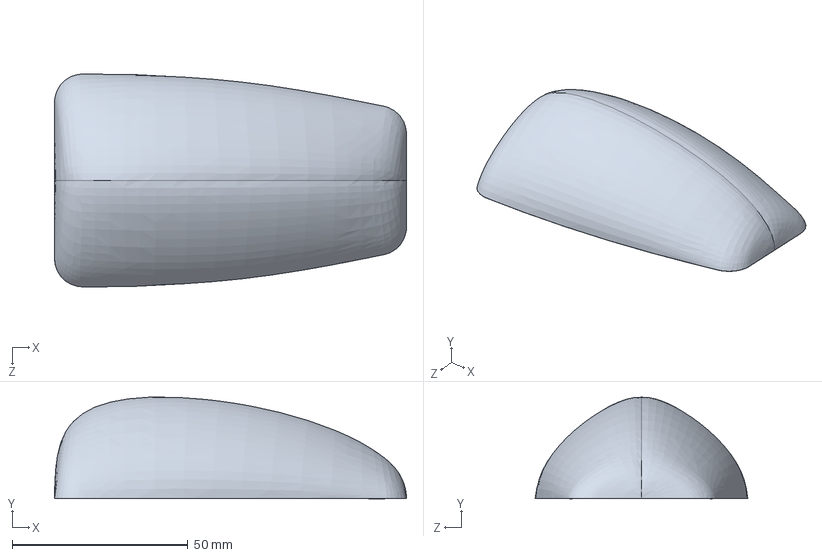
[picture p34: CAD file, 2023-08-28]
Enclosure/Conceptual Design/Body2.SLDPRT
100.0 x 28.9 x 60.5 mm

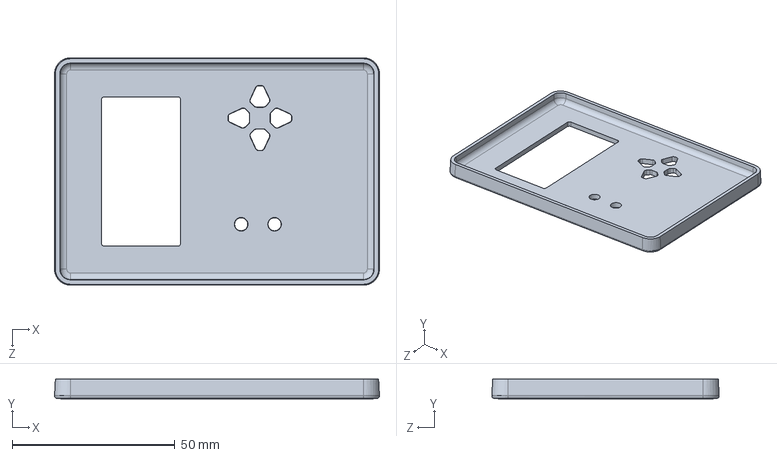
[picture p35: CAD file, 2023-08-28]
Enclosure/Final Design/Body bottom.SLDPRT
99.9 x 6.00 x 69.9 mm

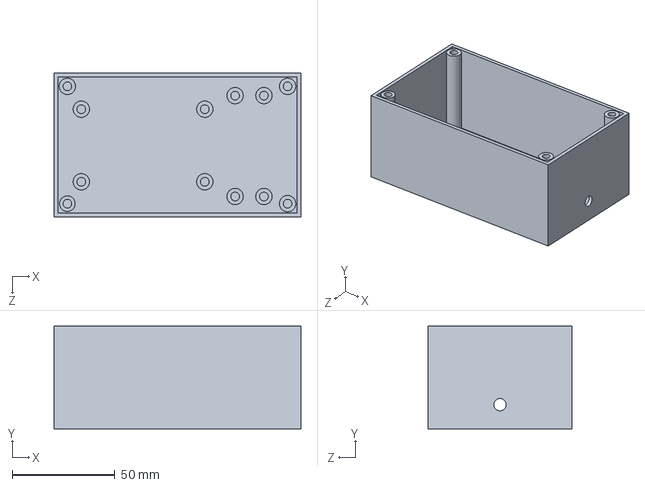
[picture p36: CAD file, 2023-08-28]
Enclosure/Final Printed Designs/final print bottom.SLDPRT
120.0 x 50.0 x 70.0 mm

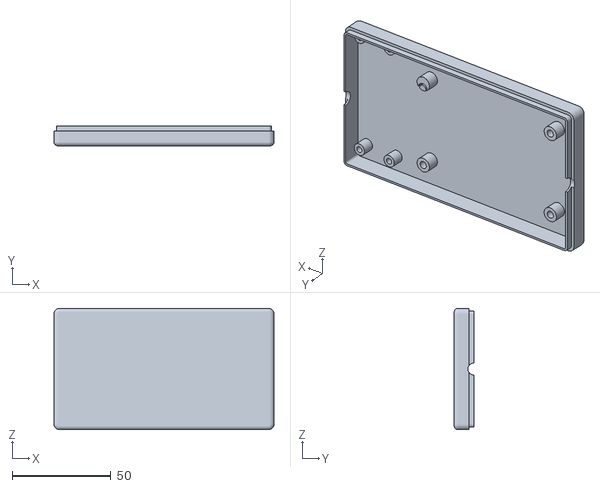
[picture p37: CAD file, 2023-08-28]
Enclosure/Final Printed Designs/New folder/Bottom.STL
111.7 x 10.0 x 61.7

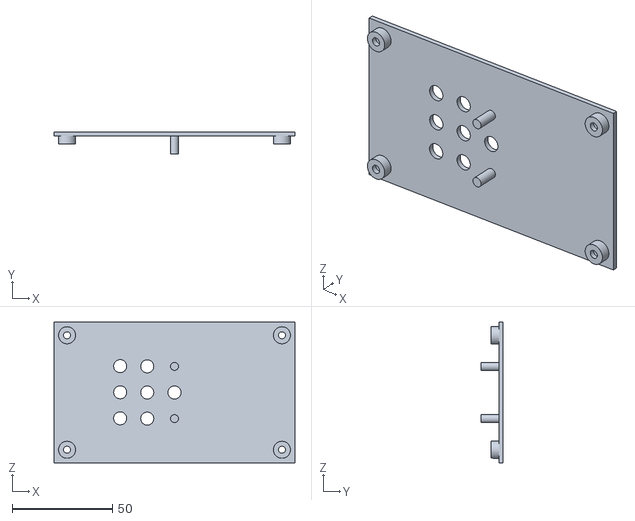
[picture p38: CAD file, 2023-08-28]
Enclosure/Final Printed Designs/second edition/Xyder/final print top.STL
120.0 x 11.0 x 70.0

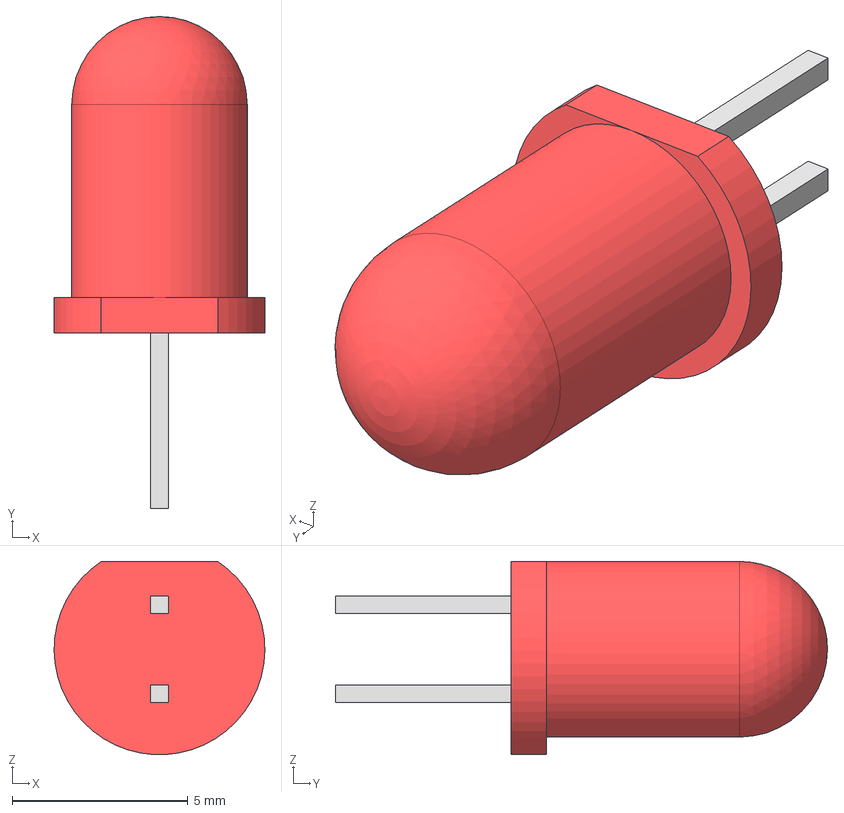
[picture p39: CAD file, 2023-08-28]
Enclosure/Initial Design/Solidworks/BTG_901_BT_001_LED_5mm_Rot/LED_5mm_Rot.stp
6.00 x 14.0 x 5.49 mm

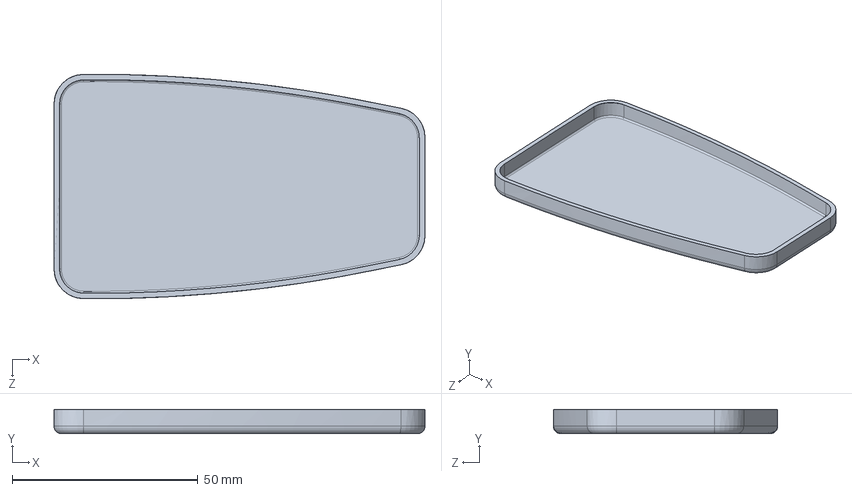
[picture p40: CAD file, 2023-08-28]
Enclosure/Conceptual Design/Body1.SLDPRT
100.0 x 6.54 x 60.5 mm

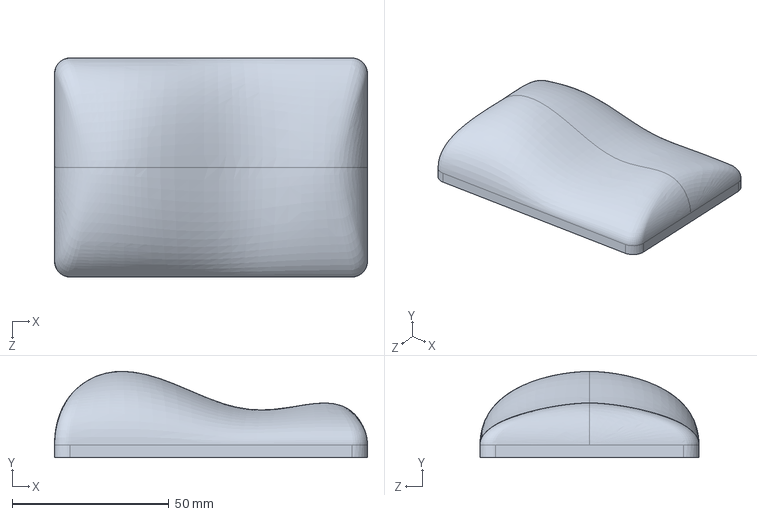
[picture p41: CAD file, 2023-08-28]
Enclosure/Final Design/Body top.SLDPRT
100.0 x 27.5 x 70.0 mm

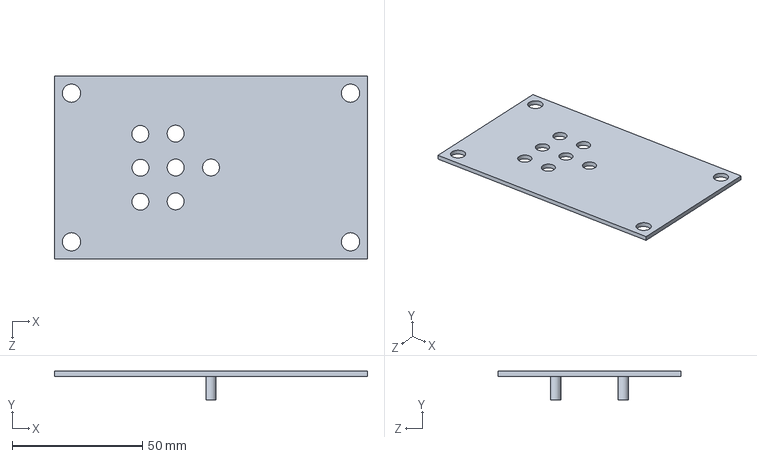
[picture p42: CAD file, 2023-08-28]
Enclosure/Final Printed Designs/final print top.SLDPRT
120.0 x 11.0 x 70.0 mm

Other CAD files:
Enclosure/Initial Design/Solidworks/Timer final.SLDASM
Enclosure/Final Printed Designs/new print/botom.STL
Enclosure/Final Printed Designs/Xyder/final print bottom.STL
Enclosure/Initial Design/Solidworks/BTG_901_BT_002_LED_5mm_Yellow/LED_5mm_Yellow.stp
Enclosure/Initial Design/Solidworks/BTG_901_BT_003_LED_5mm_Green/LED_5mm_Green.stp
Enclosure/Preliminary Design/Bottom.SLDPRT
Enclosure/Conceptual Design/Bottom.SLDPRT
Enclosure/Final Printed Designs/New folder/Top.STL
Enclosure/Final Printed Designs/Printing bottom.STL
Enclosure/Final Printed Designs/Xyder/final print top.STL
Enclosure/Final Printed Designs/new print/printing lid.STL
Enclosure/Final Printed Designs/past solidworks versioon/Body1.SLDPRT
Enclosure/Final Printed Designs/past solidworks versioon/Body2.SLDPRT
Enclosure/Final Printed Designs/past solidworks versioon/Bottom.SLDPRT
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

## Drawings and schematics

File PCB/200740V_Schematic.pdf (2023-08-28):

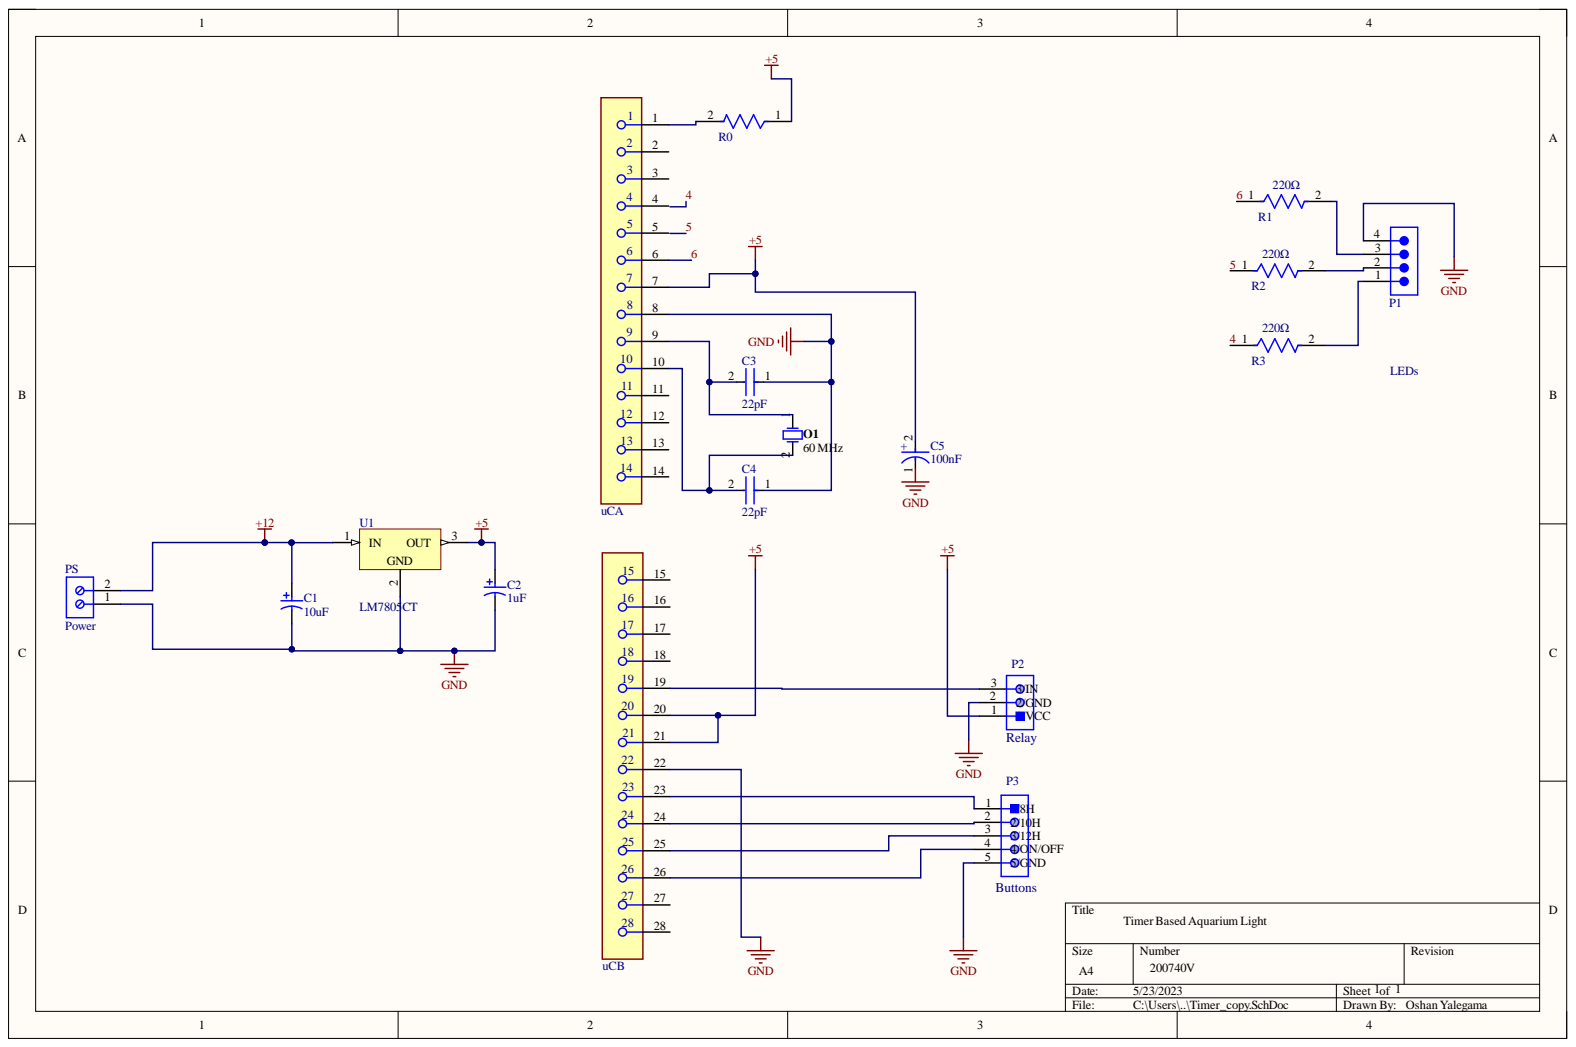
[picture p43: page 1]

3 | 5/G

Siz e A4 | Numb e r 20074 0 V | R evisio n

Da te : 5/23/202 3 | She et of 1 1
File : C:\Use rs\. .\Time r_cop y. S c hD o c | Dr awn B y : Oshan Yale g ama

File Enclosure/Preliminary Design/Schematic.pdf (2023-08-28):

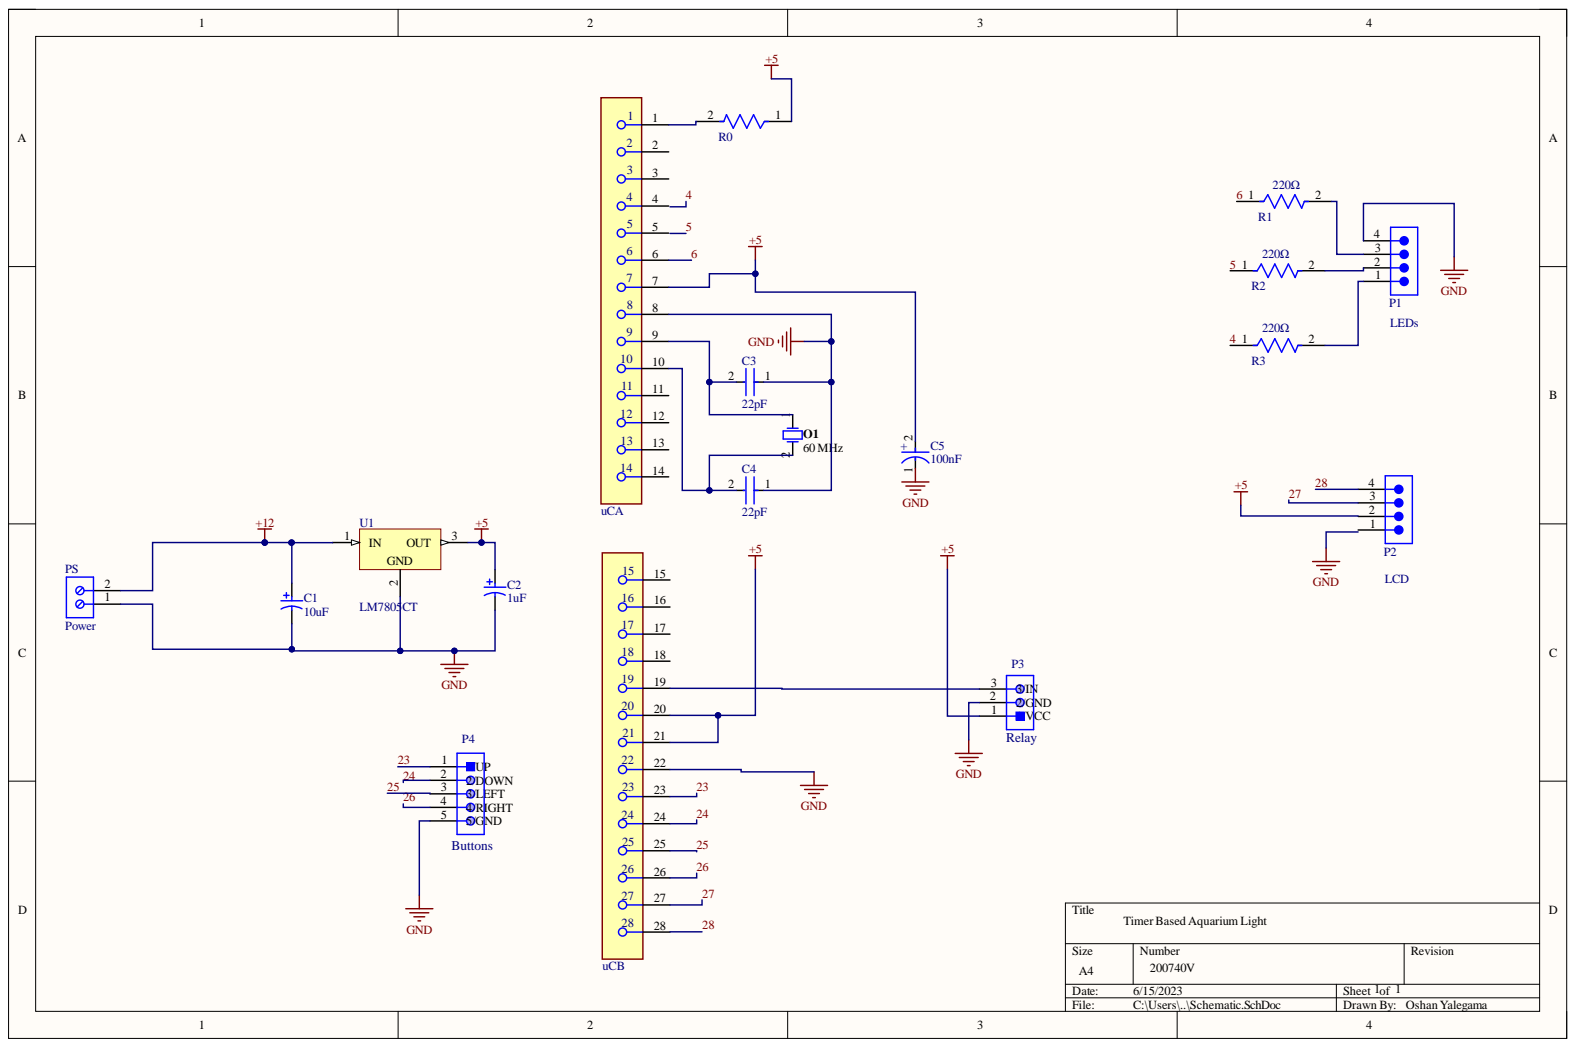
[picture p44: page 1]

Siz e A4 | Numb e r 20074 0 V | R evisio n

Da te : 6/15/202 3 | She et of 1 1
File : C:\Use rs\. .\S chemati c . S c hD o c | Dr awn B y : Oshan Yale g ama

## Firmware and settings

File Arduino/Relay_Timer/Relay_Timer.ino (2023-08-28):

int pin = 13;  // The pin we're using
int ledPin = 12;
int pin1 = 4; // green
int pin2 = 5; // yellow
int pin3 = 6; // red
long duration1 = 10000;  // The duration for button 1 (1 minute)
long duration2 = 20000;  // The duration for button 2 (5 minutes)
long duration3 = 30000;  // The duration for button 3 (30 minutes)
int buttonPin1 = A0;  // The pin for button 1
int buttonPin2 = A1;  // The pin for button 2
int buttonPin3 = A2;  // The pin for button 3
int buttonPin4 = A3; //the toggle pin
bool buttonState1 = false;  // The state of button 1 (pressed or not pressed)//A0,23, 8H
bool buttonState2 = false;  // The state of button 2 (pressed or not pressed)//A1,24
bool buttonState3 = false;  // The state of button 3 (pressed or not pressed)//A2.25
unsigned long startTime;  // The time the pin was turned on

unsigned long pressTime;
bool reset = false;

int buttonState = 0;        // variable for storing the button state
int ledState = LOW; 

int resetTime = 5000;

void setup() {
  pinMode(pin, OUTPUT);  // Set the pin as an output
  pinMode(pin1, OUTPUT);
  pinMode(pin2, OUTPUT);
  pinMode(pin3, OUTPUT);
  pinMode(buttonPin1, INPUT_PULLUP);  // Set the button 1 pin as an input with pullup resistor
  pinMode(buttonPin2, INPUT_PULLUP);  // Set the button 2 pin as an input with pullup resistor
  pinMode(buttonPin3, INPUT_PULLUP);  // Set the button 3 pin as an input with pullup resistor
  pinMode(buttonPin4, INPUT_PULLUP);
  Serial.begin(9600);  // Initialize serial communication
}

void loop() {
  buttonState1 = digitalRead(buttonPin1);  // Read the state of button 1
  buttonState2 = digitalRead(buttonPin2);  // Read the state of button 2
  buttonState3 = digitalRead(buttonPin3);  // Read the state of button 3
  buttonState = digitalRead(buttonPin4);

//  digitalWrite(ledPin, HIGH);
//  delay(1000); // Wait for 1 second
//
//  // Turn the LED off
//  digitalWrite(ledPin, LOW);
//  delay(1000); // Wait for 1 second
//  
  if (buttonState == LOW) {
    ledState = !ledState;
    digitalWrite(pin, ledState);
    delay(500);  // Debounce delay to prevent rapid toggling
  }
  
  if (buttonState1 == LOW) {  // If button 1 is pressed
    digitalWrite(pin1, HIGH);
    digitalWrite(pin, HIGH);  // Turn the pin on
    startTime = millis();  // Store the time the pin was turned on
    while (millis() - startTime <= duration1) {  // While the pin should be on
//      digitalWrite(ledPin, HIGH);
//      delay(1000); // Wait for 1 second
//
//      // Turn the LED off
//      digitalWrite(ledPin, LOW);
//      delay(1000); // Wait for 1 second
  
      //RESET Code
      buttonState = digitalRead(buttonPin4);
      if (buttonState == LOW){
        pressTime = millis();
        reset = true;
        while (millis() - pressTime <= resetTime){
          buttonState = digitalRead(buttonPin4);
          if (buttonState == HIGH){
            
            reset = false;
          }
        }
        if (reset){
          Serial.println("Stopped");
          break;
        }
      }
      //TIME PRINTING CODE
      Serial.print("Time remaining: ");
      Serial.print((duration1 - (millis() - startTime)) / 1000);  // Calculate and print the time remaining
      Serial.println(" seconds");
      delay(1000);  // Wait for one second
    }
    digitalWrite(pin1, LOW);
    digitalWrite(pin, LOW);  // Turn the pin off
    Serial.println("Done");  // Print a message when the pin is turned off
    delay(1000);  // Wait for a second before starting again
  }
  
  if (buttonState2 == LOW) {  // If button 1 is pressed
    digitalWrite(pin2, HIGH);
    digitalWrite(pin, HIGH);  // Turn the pin on
    startTime = millis();  // Store the time the pin was turned on
    while (millis() - startTime <= duration2) {  // While the pin should be on
      //COLOUR CHANGING CODE
      if (millis() - startTime >= (duration2- duration1)) {
        digitalWrite(pin2, LOW);
        digitalWrite(pin1, HIGH);
      }
//      digitalWrite(ledPin, HIGH);
//      delay(1000); // Wait for 1 second
//
//      // Turn the LED off
//      digitalWrite(ledPin, LOW);
//      delay(1000); // Wait for 1 second
  
      //RESET Code
      buttonState = digitalRead(buttonPin4);
      if (buttonState == LOW){
        pressTime = millis();
        reset = true;
        while (millis() - pressTime <= resetTime){
          buttonState = digitalRead(buttonPin4);
          if (buttonState == HIGH){
            
            reset = false;
          }
        }
        if (reset){
          Serial.println("Stopped");
          break;
        }
      }
      Serial.print("Time remaining: ");
      Serial.print((duration2 - (millis() - startTime)) / 1000);  // Calculate and print the time remaining
      Serial.println(" seconds");
      delay(1000);  // Wait for one second
    }
    digitalWrite(pin2, LOW);
    digitalWrite(pin1, LOW);
    digitalWrite(pin, LOW);  // Turn the pin off
    Serial.println("Done");  // Print a message when the pin is turned off
    delay(1000);  // Wait for a second before starting again
  }

  if (buttonState3 == LOW) {  // If button 1 is pressed
    digitalWrite(pin3, HIGH);
    digitalWrite(pin, HIGH);  // Turn the pin on    
    startTime = millis();  // Store the time the pin was turned on
    while (millis() - startTime <= duration3) {  // While the pin should be on
      //COLOUR CHANGING CODE
      if (millis() - startTime >= (duration3-duration2)) {
        if (millis() - startTime >= (duration3 - duration1)) {
           digitalWrite(pin2, LOW);
           digitalWrite(pin1, HIGH);
        }
        else{
           digitalWrite(pin3, LOW);
           digitalWrite(pin2, HIGH);
        }
      }
//      digitalWrite(ledPin, HIGH);
//      delay(1000); // Wait for 1 second
//
//      // Turn the LED off
//      digitalWrite(ledPin, LOW);
//      delay(1000); // Wait for 1 second
//  
      //RESET Code
      buttonState = digitalRead(buttonPin4);
      if (buttonState == LOW){
        pressTime = millis();
        reset = true;
        while (millis() - pressTime <= resetTime){
          buttonState = digitalRead(buttonPin4);
          if (buttonState == HIGH){
            
            reset = false;
          }
        }
        if (reset){
          Serial.println("Stopped");
          break;
        }
      }
      Serial.print("Time remaining: ");
      Serial.print((duration3 - (millis() - startTime)) / 1000);  // Calculate and print the time remaining
      Serial.println(" seconds");
      delay(1000);  // Wait for one second
    }
    digitalWrite(pin3, LOW);
    digitalWrite(pin2, LOW);
    digitalWrite(pin1, LOW);
    digitalWrite(pin, LOW);  // Turn the pin off
    Serial.println("Done");  // Print a message when the pin is turned off
    delay(1000);  // Wait for a second before starting again
  }
}
